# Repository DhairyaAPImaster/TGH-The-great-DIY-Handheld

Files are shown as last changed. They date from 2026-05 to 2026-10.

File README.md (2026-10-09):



# TGH - THE GREAT (DIY) HANDHELD
So yeah this is me trying to make my own custom retro handheld gaming device with a custom pcb powered by a pi zero 2w.

**BTW NOTE:** the case shall be printed by someone who was willing to print it from the slack channel - #printing-legion.

***very VERY IMPORTANT NOTE TO MACONDO REVIWER ---> SO IN THE BOM U MIGHT SEE THAT THE QTY OF SOME OF THE COMPONENTS FROM ROBU.IN IS MORE THAN REQUIRED THIS IS BECAUSE ROBU.IN HAS A MINIMUM ORDER QTY OF 10 INDIAN RUPEES PER COMPONENT SO HENCE I HAD TO LIKE INCREASE THE QTY OF SOME OF THE PASIVE COMPOENNTS TO LIKE FOLLOW THIS. BTW ITS STILL LIKE WAY WAY CHEAPER THAN JLCPCB'S PCBA THAT WOULD HAVE BROUGHT THE TOTAL COST TO 199.56 USD EXCLUDING TAX (I CHECKED)***

## project layout

```
.
├── `Assembly Layered.step`
├── `Assembly.step`
├── `wiring diagram.png`
├── `Custom Firmware!!!!!!!!!!/`
│   ├── `Launcher.py`
│   ├── `roms/`
│   │   ├── `GB/`
│   │   ├── `GBA/`
│   │   ├── `GBC/`
│   │   ├── `GEN/`
│   │   ├── `NES/`
│   │   ├── `SMS/`
│   │   └── `SNES/`
│   ├── `saves/`
│   └── `states/`
├── `production files/`
│   ├── `CAD/`
│   └── `PCB/`
│       ├── `MAIN PANELISED PCB (TO BE MANUFACTURED)/`
│       ├── `Mother board (not to be manufactured)/`
│       ├── `left daughter board (not to be manufactured)/`
│       └── `right daughter board (not to be manufactured)/`
└── `src/`
		├── `FreeCAD/`
		└── `PCB/`

```

## quick specs
- Panelised PCB Dimensions - 339.82 mm x 102.32 mm
- the only KiCAD plugin i used was KiKit to panelise the board, everything else was designed by me (this is my first major PCB project)

## WIRING DIAGRAM



## HOW TO RECREATE THIS PROJECT YOURSELF!!! 
- Step 1 - Basically Just Clone or downlaod this repo from github. U can do this by either going to the code button on this repo page and pressing download Zip or u can clone this Repo.
- Step 2 - Upload the gerbers zip file in JLCPCB (or any other manufacturer) Place order Page (u will need to sign up to order but can get a quote without signing up on jlcpcb)
- Step 3 - Change the colour of the PCB in the options JLC gives (if u use JLC PCB most of the times canging colours does not add any charge acc to what i know)
- Step 4 - Select PCBA if u want JLCPCB to assemble the PCB for you (though it is way more expensive than just soldering everything yourself.)
- Step 5 - Upload the CPL and BOM files.(if you are getting pcba)
- Step 6 - Recheck the position of all components
- Step 7 - Add to cart and order the PCB!! **(if you are soldering the components yourself you will need to buy them from some other place im mainly using robu.in and some components froma amzon and others)**
- Step 8 - If you dont have a 3D PRINTER jlcpcb has a 3d printing service too caled JLC3DP so u can upload the files for the case there and get it printed too but if u have a 3d printer you can just print it youreslf and save a lot of money.
- Step 9 - Order strong epoxy glue or superglue that does not cause harm to the 3d printed case material (I will be using FeviQuick as it should not cause harm to PLA in which the case will be printed)
- Step 10 - WAIT WAIT WAIT for your parts to be delhivered
- Step 11 - Once you have the PCB you will need to connect the daughter boards to the main motherboard using wires or an FFC connector i will be using solid code jumper wires since they are the easiest.
- Step 12 - If you are hand soldering the components you need to hand solder them according to the PCB Design that you can find by opening the project in kicad.
- Step 13 - Once you have all the parts ready (PCB, CASE and the appropriate Glue) place the PCB in the Case (you might have to trim the spacers down a bit as i made the spacers high so that they arent to small as i can always cut higher spacers down but can not extend spacers that are short.)  Use hot glue to secure the PCB onto the Spacers (btw if you have a smaller 3d printer you will have to like print the case in parts or diagonaly as it is slightly bigger than like the a1 mini and others of that size)
- Step 14 - Once the PCB is secured inside the case glue the Top Part of the Case shut after attatching the button caps onto the switches and adjusting the spacing of the screen.
- Step 15 - BOOM  THERE YOU HAVE IT THE PHYSICAL HARDWARE IS DONE NOW THE FIRMWARE.....

- Step 16 - To run the firmware first flash RASPBERRY PI OS onto the raspberry pi

- Step 17 - Put the microSD card into the Raspberry Pi Zero 2 W and power it on. Give it a little bit of time to boot for the first time. If you are using the Pi by itself for the initial setup, connect it to a display and keyboard so you can configure everything.

- Step 18 - Clone this repository onto the Raspberry PiThen enter the firmware folder:

	`TGH-The-great-DIY-Handheld/"Custom Firmware!!!!!!!!!!`

	The firmware folder should look something like this:
	```
	Custom Firmware!!!!!!!!!!
	├── Launcher.py
	├── roms/
	│   ├── GB/
	│   ├── GBA/
	│   ├── GBC/
	│   ├── GEN/
	│   ├── NES/
	│   ├── SMS/
	│   └── SNES/
	├── saves/
	└── states/
	```

 - Step 19 - If everything is working correctly, the TGH launcher should start.

 - ALMOST LAST STEP - ADD YOUR ROMS to there respective folders in the firmware folder
	Basically:

	Game Boy ROM → `GB/`

	Game Boy Advance ROM → `GBA/`

	Game Boy Color ROM → `GBC/`

	Genesis ROM → `GEN/`

	NES ROM → `NES/`

	Sega Master System ROM → `SMS/`

	SNES ROM → `SNES/`

- TRUE LAST STEP - CONNECT EVERYTHING TO THE CUSTOM PCB

- **RECOMMENDED** - Before closing the case, test:

Does the Pi boot?
Does the display work?
Does the launcher start?
Do the buttons work?
Do the joysticks work?
Does audio work?
Does the speaker work?
Does the headphone jack work?
Does the power system work?
Do games launch?
Do saves/states work?

If all of those work (IF U DO IT CORRECTLY IT WILL WORK) THEN..... 
## BOOM!!!! YOU HAVE A WORKING RETRO HANDHELD GAMING DEVICE!!!!!!

## BOM/BILL OF MATERIALS (PARTS I NEED FUNDING FOR)

| Name | Purpose | Quantity | Total Cost (USD) | Link | Distributor |
|---|---|---|---|---|---|
| PCB from JLCPCB  | it is the main PCB and will connect all components to each other. (btw JLCPCB has min order qty for PCB as 5 so yeah) | 5 | 18.4 | https://cart.jlcpcb.com/ | JLCPCB |
| Raspberry Pi Zero | its basically the core of the whole project it shall basically run everything. | 1 | 19.08 | https://robu.in/product/raspberry-pi-zero-wireless-wh-pre-soldered-header/ | robu.in |
| 5 Inch Touch Screen HDMI Interface TFT LCD | to display. | 1 | 26.18 | https://robu.in/product/5-inch-touch-screen-hdmi-interface-display-module-tft-lcd-800x480-raspberry-pi-2-model-b-touch-pen/ | robu.in |
| Mini HDMI To HDMI Cable | to connect pi to display | 1 | 1.08 | https://robu.in/product/mini-hdmi-hdmi-cable-1-8-meter-round-high-quality-copper-clad-steel-black/ | robu.in |
| 10 uF capacitor | to decouple more  | 15 | 0.14 | https://robu.in/product/cs2012x7r106m100nre-samwha-10v-10uf-x7r-%c2%b120-0805-multilayer-ceramic-capacitors-mlcc-smd-smt-rohs/ | robu.in |
| 100nF capacitor | to decouple | 20 | 0.14 | https://robu.in/product/tcc0805x7r104k500dt-cctc-smt-ceramic-capacitors-0805-x7r-104k100nf%c2%b110-rated-voltage50v-thickness0-85mmtape/ | robu.in |
| 6x6x5mm tactile switches | to well be used as switches and for the buttons controlling everything. | 10 | 0.14 | https://robu.in/product/6x6x5mm-tactile-push-button-switch-pack-of-20/ | robu.in |
| MAX98358ETE | audio amplifier | 1 | 2.62 | https://robu.in/product/1-month-warranty-560/ | robu.in |
| MT3608  IC | to take a lower DC voltage and steps it up to a higher, adjustable DC voltage | 2 | 0.28 | https://robu.in/product/mt3608-xian-aerosemi-tech-boost-type-adjustable-2a-2v24v-sot-23-6-dc-dc-converters-rohs/ | robu.in |
| 33 µH BOURNS-SRR1260-330M-Power Inductor (SMD) | to stores energy in a magnetic field and resists changes in electrical current. | 1 | 0.67 | https://robu.in/product/srr1260-330m-bourns-srr1260-330m-power-inductor-smd-33-%c2%b5h-3-a-shielded-2-8-a-srr1260-series/ | robu.in |
| SOD-123 Schottky Diodes ROHS | used to allow current to flow in one direction. | 2 | 0.12 | https://robu.in/product/1n5819w-kexin-40v-600mv1a-1a-sod-123-schottky-diodes-rohs/ | robu.in |
| 100 ohm resistor | to resist current | 25 | 0.12 | https://robu.in/product/rc0805jr-07100rl-yageo-res-thick-film-0805-100-ohm-5-0-125w1-8w-%c2%b1100ppm-c-pad-smd-t-r/ | robu.in |
| 4.7k ohm resistor | to resist  | 29 | 0.12 | https://robu.in/product/yageo-4-7k-ohm-1-4w-0805-surface-mount-resistor-pack-of-50/ | robu.in |
| 10k ohm resistor | im legit tired of writing the same thing again for all the resistor but anyways ---> IT resists the flow of current. | 20 | 0.12 | https://robu.in/product/rc0805fr-0710kl-yageo-res-thick-film-0805-10k-ohm-1-0-125w1-8w-%c2%b1100ppm-c-pad-smd-t-r/ | robu.in |
| 20k ohm resistor | u are not gonna belive what this does ---> IT resists the flow of current.... | 29 | 0.12 | https://robu.in/product/rc0805fr-0720kl-yageo-res-thick-film-0805-20k-ohm-1-0-125w1-8w-%c2%b1100ppm-c-pad-smd-t-r/ | robu.in |
| 33k ohm resistor | to resist!!!!! | 20 | 0.12 | https://robu.in/product/rc0805fr-0733kl-yageo-res-thick-film-0805-33k-ohm-1-0-125w1-8w-%c2%b1100ppm-c-pad-smd-t-r/ | robu.in |
| 100k ohm 0805 resistor | to resist flow of current? | 23 | 0.12 | https://robu.in/product/yageo-100k-ohm-1-2w-0805-surface-mount-resistor-pack-of-50/ | robu.in |
| D6.3xL11mm Aluminum Electrolytic Capacitors | its a capacitor dude like it provides capacitance (idk what do i write under Purpose) | 4 | 0.18 | https://robu.in/product/16yxf100mefct16-3x11-rubycon-100uf-16v-%c2%b120-plugind6-3xl11mm-aluminum-electrolytic-capacitors-leaded-rohs/ | robu.in |
| 22µF SMT 0805 capacitor | To provide capacitance | 10 | 0.18 | https://robu.in/product/tcc0805x5r226k100ft-cctc-smt-ceramic-capacitors-0805-x5r-226k22%c2%b5f%c2%b110-rated-voltage10v-thickness1-25mmtape/ | robu.in |
| TP4056 1A Li-Ion Battery Charging Board | To charge the battery  | 1 | 0.17 | https://robu.in/product/tp4056-1a-li-ion-battery-charging-board-micro-usb-with-current-protection-type-c-connector/ | Robu.in |
| 1mm Pitch Pin headers | These are seperate as the previous headers are not 1mm pitch pin headers. | 1 | 0.21 | https://robu.in/product/1-month-warranty-884/ | Robu.in |
| 3.5mm Female Audio Jack Connector  | to attach headphones | 1 | 0.47 | https://evelta.com/3-5mm-female-audio-jack-connector-6pin-1/ | Evelta.com |
| ADS1115IDGSR - 16-Bit ADC 2, 4 Input 1 Sigma-Delta IC VSSOP-10 | to convert analog voltage signals into digital data  | 1 | 1.94 | https://evelta.com/ads1115idgsr-16-bit-adc-2-4-input-1-sigma-delta-ic-vssop-10/ | Evelta.com |
| PS2 Game Joystick Module | For the Joysticks | 2 | 0.82 | https://www.flyrobo.in/ps2_game_joystick_module_for_arduino | FlyRobo |
| Male and Female Header Connector Strip, Pack of 10, Breakable Strip | For the pin Headers (btw this was a cheap pack of 10 and is actually cheaper than buying each header individually) | 1 | 1.27 | https://www.amazon.in/gp/product/B0FQP3SN7H/ref=ox_sc_act_image_8?smid=ATNZHHWX66S9H&psc=1 | Amazon |
| SPDT Slide Switch Right Angle | TO turn on and off | 1 | 1.0 | https://www.amazon.in/gp/product/B0B434R6QF/ref=ox_sc_act_image_7?smid=A2JDRZEGU1IDE2&psc=1 | Amazon |
| 0.5Watt Power Audio Speaker | For sound | 1 | 1.21 | https://www.amazon.in/gp/product/B07MTK843Z/ref=ox_sc_act_image_6?smid=AJ6SIZC8YQDZX&psc=1 | Amazon |
| Isopropyl Alcohol | For cleaning Board after soldering. | 1 | 2.95 | https://www.amazon.in/gp/product/B0DXLCF467/ref=ox_sc_act_image_5?smid=A66YHFPLB5NLO&th=1 | Amazon |
| Tactile Push Button Switch Caps | To button | 1 | 2.34 | https://www.amazon.in/gp/product/B0DCP7J7R7/ref=ox_sc_act_image_4?smid=AOG7U64E0DVL2&psc=1 | Amazon |
| Jumper Wires | For fine adjustment if required | 1 | 1.66 | https://www.amazon.in/gp/product/B0CPFCRCHB/ref=ox_sc_act_image_3?smid=AJ6SIZC8YQDZX&th=1 | Amazon |
| Solder  | to solder | 1 | 8.37 | https://www.amazon.in/gp/product/B084RZWVXY/ref=ox_sc_act_image_2?smid=AVIYBMAJK8N56&th=1 | Amazon |
| Soldering Flux | Helping to solder. | 1 | 0.84 | https://www.amazon.in/gp/product/B0FV8HHBTN/ref=ox_sc_act_image_1?smid=A366YFPXO3CTI5&psc=1 | Amazon |

## fab note
- so i plan on using JLCPCB to actually get my boards manufactured (i checked and for the size of this project's pcb getting the pcb from robu.in is way more expensive than jlcpcb) but will be ASSEMBLING THE COMPONENTS BY HAND!!!!

## pics from while i was designing it
















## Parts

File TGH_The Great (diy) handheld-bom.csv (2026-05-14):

Name | Purpose | Quantity | Total Cost (USD) | Link | Distributor
Solder | I cant solder witout solder and i have like 1cm or so left as i used the rest before my soldering iron short cicuited. | 1 | 7.75 | https://www.amazon.in/SONEAK-Solder-Rosin-Electrical-Soldering/dp/B084RZWVXY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 | Amazon
Soldering Flux | To help solder and not have cold solder joints. | 1 | 0.83 | https://www.amazon.in/UNIVERSAL-HUB-Soldering-Electronics-components/dp/B0FV8HHBTN | Amazon
Soldering Iron | Mine short circuited and i need to solder a buch of stuff on the pcb which i cant without the iron | 1 | 3.02 | https://www.amazon.in/Temperature-Adjustable-Soldering-Heating-Extra/dp/B0DPVMRTXG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 | amazon
Soldering Helping hands | Too see what i am soldering and to help solder properly without burning anything by mistake. | 1 | 5.35 | https://robu.in/product/te-801-multi-function-led-magnifier-pcb-soldering-iron-stand-holder-table-magnifying-glass-35x-12x-w-2-led-light/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 | Robu.in
JST SH 2 pin Connector 2mm Pitch | to connect battery | 1 | 0.02 | https://robu.in/product/jst-sh-2-pin-connector-2mm-pitch/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 | Robu.in
Mini HDMI To HDMI Cable | to connect pi to display | 1 | 1.30 | https://robu.in/product/mini-hdmi-hdmi-cable-1-8-meter-round-high-quality-copper-clad-steel-black/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 | Robu.in
40mm 8Ω (ohm) 0.5Watt Power Audio Speaker - Multicolor | to produce sound | 1 | 1.66 | https://www.amazon.in/Electronic-Spices-Wired-Sound-Speakers/dp/B07MTK843Z | amazon
PS2 joystick module | Left and right joystick | 2 | 0.79 | https://www.flyrobo.in/ps2_game_joystick_module_for_arduino?tracking=ads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 | FlyRobo
000mAh 3.7V Micro LiPo Battery pack | To power the device | 1 | 5.64 | https://robu.in/product/nova-955465-4000mah-3-7v-lipo-battery-pack/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 | Robu.in
100 uF 10V Through Hole Electrolytic Capacitor | headphone blocking on PCB | 2 | 0.04 | https://robu.in/product/100-uf-10v-through-hole-electrolytic-capacitor-pack-of-20/?gad_source=1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 | Robu.in
3mm Green LED | To show charging finished | 1 | 0.02 | https://robu.in/product/5mm-green-surface-mount-led-pack-of-50/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 | Robu.in
3mm Red LED | To see the charging | 1 | 0.02 | https://robu.in/product/3mm-red-dip-led-pack-of-50/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 | Robu.in
6mm Tactile Push Button Switch 6x6 (Pack of 10) | For buttoning | 1 | 0.14 | https://robu.in/product/6x6x5-tactile-push-button-switch/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 | Robu.in
Slide switch SPDT | To switch on the device | 1 | 0.09 | https://robu.in/product/1-month-warranty-805/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 | Robu.in
USB Type C, 2.0, 16P, Receptacle, Horizontal,Top Mount, Thru-Hole | Charging | 1 | 0.80 | https://www.mouser.in/ProductDetail/GCT/USB4920-00-A?qs=vcFyY%252BOcAygpR4IfeDpXRQ%3D%3D | Mouser
1x5 2.54mm Female Right Angle Single Row Header Strip | For Connecting the left and right joystick Modules | 2 | 0.26 | https://www.sunrom.com/p/1x5-254mm-female-right-angle-single-row-header-strip | sunrom.com
1x2 male pin header 2.54mm | For supplying power to the display and speaker | 3 | 0.69 | https://robu.in/product/a2541wv-2p-9t-cjt-1x2-pin-2-54mm-180-single-row-pin-header-rohs/?gad_source=1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 | Robu.in
2.54MM 2x20 Pin Female Double Row Straight Long Header Strip | To connect the Pi to the PCB | 1 | 0.86 | https://robu.in/product/2-54mm-2x20-pin-female-double-row-straight-long-header-strip/?gad_source=1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 | Robu.in
5 Inch Touch Screen HDMI Interface | THE SCREEN To See what i am playing | 1 | 26.09 | https://robu.in/product/5-inch-touch-screen-hdmi-interface-display-module-tft-lcd-800x480-raspberry-pi-2-model-b-touch-pen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 | Robu.in
Raspberry Pi Zero 2W | This is basically the Brain of the device it shall run RetroPie | 1 | 18.81 | https://robu.in/product/raspberry-pi-zero-wireless-wh-pre-soldered-header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 | Robu.in
PCBA for bottom SMD components on PCB | PCB SMD comlponent assembly since idk how to solder SMD components :( | 2 | 78.32 | https://jlcpcb.com | JLCPCB
PCB (Motherboard, and both daughter boards) | Basically the heart of the device. These are the custom PCB's that i have made for the handheld gaming device these shall hold all components and connect them. | 5 | 18.00 | https://jlcpcb.com | JLCPCB

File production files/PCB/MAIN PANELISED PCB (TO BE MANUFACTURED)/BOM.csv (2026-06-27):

Id | Designator | Footprint | Quantity | Designation | Supplier and ref
1 | Battery_3.7V1 | PinHeader_1x02_P2.54mm_Vertical | 1 | Conn_01x02
2 | C3 | C_0805_2012Metric | 1 | 22µF
3 | C4 | C_0805_2012Metric | 1 | 22uF
4 | C5 | C_0805_2012Metric | 1 | 10uF
5 | C6 | C_0805_2012Metric | 1 | 100nF
6 | C7, C8 | CP_Radial_D6.3mm_P2.50mm | 2 | 100µF
7 | D3 | D_SOD-123 | 1 | 1N5819
8 | J1 | PinHeader_2x20_P2.54mm_Vertical | 1 | Conn_02x20_Odd_Even
9 | J2 | PinHeader_1x02_P2.54mm_Vertical | 1 | TP4056_Module
10 | J3 | PinSocket_1x05_P2.54mm_Horizontal | 1 | Joystick_Left
11 | J4 | PinSocket_1x05_P2.54mm_Horizontal | 1 | Joystick_Right
12 | J5 | PinHeader_1x02_P2.54mm_Vertical | 1 | Display_5V
13 | J6 | PinHeader_1x02_P2.54mm_Vertical | 1 | Speaker
14 | J7 | Jack_3.5mm_CUI_SJ-3523-SMT_Horizontal | 1 | AudioJack3_3.5mm
15 | J10, J13 | PinHeader_1x12_P1.00mm_Vertical | 2 | FCC Connector Left Board
16 | J11, J12 | PinHeader_1x12_P1.00mm_Vertical | 2 | FCC Connector Right Board
17 | L1 | L_Bourns_SRR1260 | 1 | 22uH
18 | R4 | R_0805_2012Metric | 1 | 100k
19 | R5 | R_0805_2012Metric | 1 | 33k
20 | R6, R7, R8, R9, R10, R11, R12, R13, R14, R15, R22, R23, R28, R29 | R_0805_2012Metric | 14 | 10k
21 | R18, R19 | R_0805_2012Metric | 2 | 4.7k
22 | R20, R21 | R_0805_2012Metric | 2 | 100
23 | R24, R25, R26, R27 | R_0805_2012Metric | 4 | 20k
24 | SW1 | SW_Slide_SPDT_Angled_CK_OS102011MA1Q | 1 | SW_SPDT
25 | SW2 | SW_PUSH_6mm_H5mm | 1 | Button_A
26 | SW3 | SW_PUSH_6mm_H5mm | 1 | Button_B
27 | SW4 | SW_PUSH_6mm_H5mm | 1 | Button_X
28 | SW5 | SW_PUSH_6mm_H5mm | 1 | Button_Y
29 | SW6 | SW_PUSH_6mm_H5mm | 1 | D-pad UP
30 | SW7 | SW_PUSH_6mm_H5mm | 1 | D-pad DOWN
31 | SW8 | SW_PUSH_6mm_H5mm | 1 | D-pad LEFT
32 | SW9 | SW_PUSH_6mm_H5mm | 1 | D-pad RIGHT
33 | SW12 | SW_PUSH_6mm_H5mm | 1 | Start
34 | SW13 | SW_PUSH_6mm_H5mm | 1 | Select
35 | U2 | SOT-23-6 | 1 | MT3608
36 | U3 | TSSOP-10_3x3mm_P0.5mm | 1 | ADS1115IDGS
37 | U4 | TQFN-16-1EP_3x3mm_P0.5mm_EP1.23x1.23mm | 1 | MAX98357A

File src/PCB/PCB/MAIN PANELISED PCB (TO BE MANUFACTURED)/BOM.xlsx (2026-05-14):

Comment | Designator | Footprint
Conn_01x02 | Battery_3.7V1 | PinHeader_1x02_P2.54mm_Vertical
22µF | C3 | C_0805_2012Metric
22uF | C4 | C_0805_2012Metric
10uF | C5 | C_0805_2012Metric
100nF | C6 | C_0402_1005Metric
100µF | C7, C8 | CP_Radial_D6.3mm_P2.50mm
1N5819 | D3 | D_SOD-123
Conn_02x20_Odd_Even | J1 | PinHeader_2x20_P2.54mm_Vertical
TP4056_Module | J2 | PinHeader_1x02_P2.54mm_Vertical
Joystick_Left | J3 | PinSocket_1x05_P2.54mm_Horizontal
Joystick_Right | J4 | PinSocket_1x05_P2.54mm_Horizontal
Display_5V | J5 | PinHeader_1x02_P2.54mm_Vertical
Speaker | J6 | PinHeader_1x02_P2.54mm_Vertical
AudioJack3_3.5mm | J7 | Jack_3.5mm_CUI_SJ-3523-SMT_Horizontal
Connector Left Board | J10, J13 | PinHeader_1x12_P1.00mm_Vertical
Connector Right Board | J11 | PinHeader_1x12_P1.00mm_Vertical
Connector Right Board | J12 | PinHeader_1x12_P1.00mm_Vertical
Joystick Module Left Board | JM1 | Joystick Module 40x27mm
Joystick Module right board | JM2 | Joystick Module 40x27mm
22uH | L1 | L_Bourns_SRR1260
100k | R4 | R_0402_1005Metric
33k | R5 | R_0402_1005Metric
10k | R6, R7, R8, R9, R10, R11, R12, R13, R14, R15, R22, R23, R28, R29 | R_0402_1005Metric
4.7k | R18, R19 | R_0402_1005Metric
100 | R20, R21 | R_0402_1005Metric
20k | R24, R25, R26, R27 | R_0402_1005Metric
SW_SPDT | SW1 | SW_Slide_SPDT_Angled_CK_OS102011MA1Q
Button_A | SW2 | SW_PUSH_6mm_H5mm
Button_B | SW3 | SW_PUSH_6mm_H5mm
Button_X | SW4 | SW_PUSH_6mm_H5mm
Button_Y | SW5 | SW_PUSH_6mm_H5mm
D-pad UP | SW6 | SW_PUSH_6mm_H5mm
D-pad DOWN | SW7 | SW_PUSH_6mm_H5mm
D-pad LEFT | SW8 | SW_PUSH_6mm_H5mm
D-pad RIGHT | SW9 | SW_PUSH_6mm_H5mm
Start | SW12 | SW_PUSH_6mm_H5mm
Select | SW13 | SW_PUSH_6mm_H5mm
MT3608 | U2 | SOT-23-6
ADS1115IDGS | U3 | TSSOP-10_3x3mm_P0.5mm
MAX98357A | U4 | TQFN-16-1EP_3x3mm_P0.5mm_EP1.23x1.23mm

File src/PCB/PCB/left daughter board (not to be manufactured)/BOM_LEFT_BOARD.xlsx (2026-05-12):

Comment | Designator | Footprint
Joystick_Left | J3 | PinSocket_1x05_P2.54mm_Horizontal
FCC Connector Left Board | J10 | PinHeader_1x12_P1.00mm_Vertical
Joystick Module right board | JM2 | Joystick Module 40x27mm
10k | R10, R11, R12, R13, R14, R15, R22, R23 | R_0402_1005Metric
20k | R24, R25 | R_0402_1005Metric
D-pad UP | SW6 | SW_PUSH_6mm_H5mm
D-pad DOWN | SW7 | SW_PUSH_6mm_H5mm
D-pad LEFT | SW8 | SW_PUSH_6mm_H5mm
D-pad RIGHT | SW9 | SW_PUSH_6mm_H5mm
Start | SW12 | SW_PUSH_6mm_H5mm
Select | SW13 | SW_PUSH_6mm_H5mm

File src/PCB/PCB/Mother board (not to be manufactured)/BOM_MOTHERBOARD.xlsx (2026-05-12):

Comment | Designator | Footprint
Conn_01x02 | Battery_3.7V1 | PinHeader_1x02_P2.54mm_Vertical
10µF | C1 | C_0805_2012Metric
4.7µF | C2 | C_0805_2012Metric
22µF | C3 | C_0805_2012Metric
22uF | C4 | C_0805_2012Metric
10uF | C5 | C_0805_2012Metric
100nF | C6 | C_0402_1005Metric
100µF | C7, C8 | CP_Radial_D6.3mm_P2.50mm
RED | D1 | LED_D3.0mm
Green | D2 | LED_D3.0mm
1N5819 | D3 | D_SOD-123
Conn_02x20_Odd_Even | J1 | PinHeader_2x20_P2.54mm_Vertical
USB_C_Receptacle_USB2.0_14P | J2 | USB_C_Receptacle_GCT_USB4085
Display_5V | J5 | PinHeader_1x02_P2.54mm_Vertical
Speaker | J6 | PinHeader_1x02_P2.54mm_Vertical
AudioJack3_3.5mm | J7 | Jack_3.5mm_CUI_SJ-3523-SMT_Horizontal
FCC Connector Right Board | J12 | PinHeader_1x12_P1.00mm_Vertical
FCC Connector Left Board | J13 | PinHeader_1x12_P1.00mm_Vertical
22uH | L1 | L_Bourns_SRR1260
2K | R1 | R_0402_1005Metric
1K | R2, R3 | R_0402_1005Metric
100k | R4 | R_0402_1005Metric
33k | R5 | R_0402_1005Metric
5.1k | R16, R17 | R_0402_1005Metric
4.7k | R18, R19 | R_0402_1005Metric
100 | R20, R21 | R_0402_1005Metric
SW_SPDT | SW1 | SW_Slide_SPDT_Angled_CK_OS102011MA1Q
TP4056-42-ESOP8 | U1 | SOIC-8-1EP_3.9x4.9mm_P1.27mm_EP2.41x3.3mm_ThermalVias
MT3608 | U2 | SOT-23-6
ADS1115IDGS | U3 | TSSOP-10_3x3mm_P0.5mm
MAX98357A | U4 | TQFN-16-1EP_3x3mm_P0.5mm_EP1.23x1.23mm

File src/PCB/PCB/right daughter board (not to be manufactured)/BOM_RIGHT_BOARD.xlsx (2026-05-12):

Comment | Designator | Footprint
Joystick_Right | J4 | PinSocket_1x05_P2.54mm_Horizontal
FCC Connector Right Board | J11 | PinHeader_1x12_P1.00mm_Vertical
Joystick Module Left Board | JM1 | Joystick Module 40x27mm
10k | R6, R7, R8, R9, R28, R29 | R_0402_1005Metric
20k | R26, R27 | R_0402_1005Metric
Button_A | SW2 | SW_PUSH_6mm_H5mm
Button_B | SW3 | SW_PUSH_6mm_H5mm
Button_X | SW4 | SW_PUSH_6mm_H5mm
Button_Y | SW5 | SW_PUSH_6mm_H5mm

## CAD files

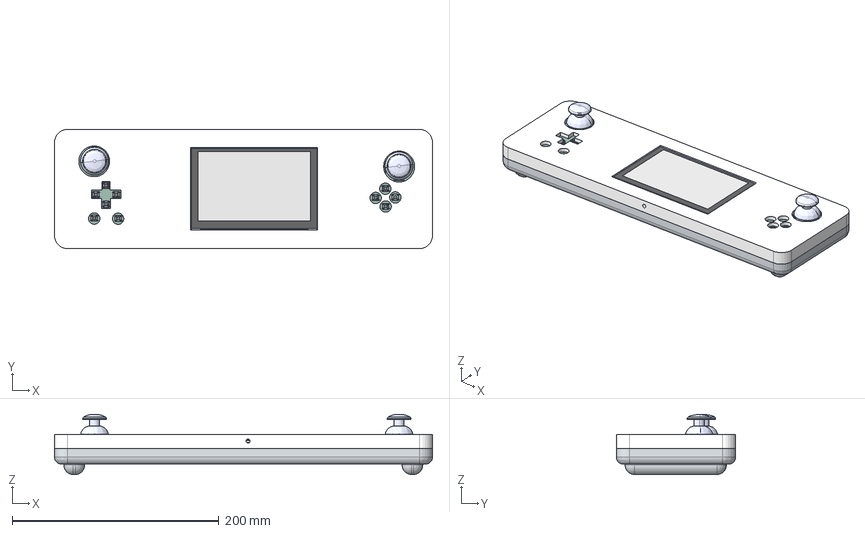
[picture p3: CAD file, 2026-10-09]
Assembly.step
365.3 x 115.3 x 58.0 mm
board
potentiometer___
potentiometer___001
tactileswitch-short
joystickhead___
Bottom Case
board001
potentiometer___002
potentiometer___003
tactileswitch-short001
joystickhead___001
Conector USB
Conector microUSB x 2
Jack_body
Jack_Pin1
Jack_Pin2
Jack_Pin3
5051102491 v1
User Library-QFP80_080 v1
PTS841GMSMTRLFS v1 x 5
4-40 3/4 inch bolt v2 x 4
5 inch lcd foot spacer v4 x 4
PinHeader_1x02_P2.54mm_Vertical x 4
PinHeader_1x12_P1.00mm_Vertical x 4
SW_PUSH_6mm_H5mm x 10
PinSocket_1x05_P2.54mm_Horizontal x 2
CP_Radial_D6.3mm_P2.50mm x 2
SW_Slide_SPDT_Angled_CK_OS102011MA1Q
PinHeader_2x20_P2.54mm_Vertical
R_0805_2012Metric x 24
C_0805_2012Metric x 4
SOT-23-6
L_Bourns_SRR1260
TSSOP-10_3x3mm_P0.5mm
D_SOD-123
Handheld_Panel_PCB

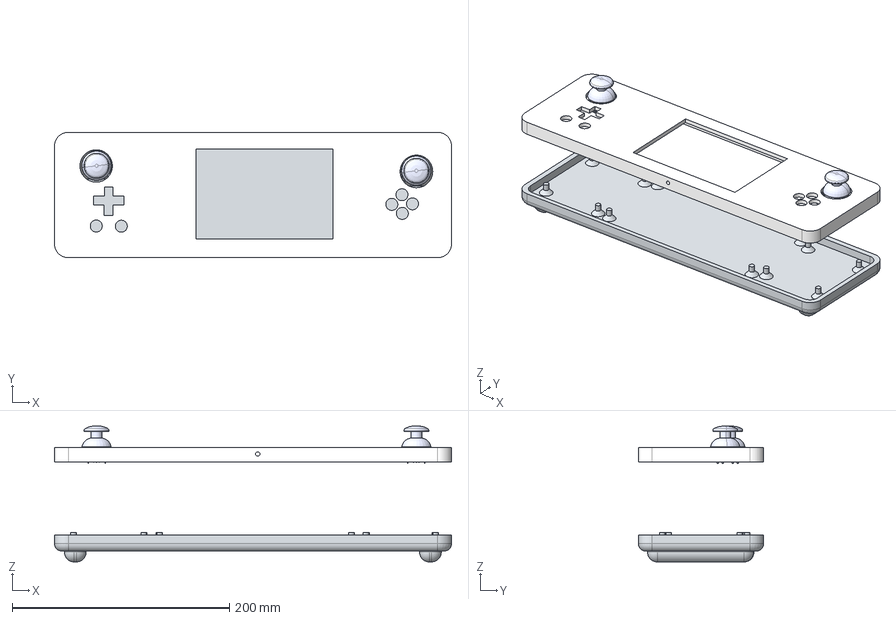
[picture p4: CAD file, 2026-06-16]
Assembly Layered.step
365.3 x 115.3 x 125.0 mm
Bottom Case
board
potentiometer___
potentiometer___001
tactileswitch-short
joystickhead___
board001
potentiometer___002
potentiometer___003
tactileswitch-short001
joystickhead___001

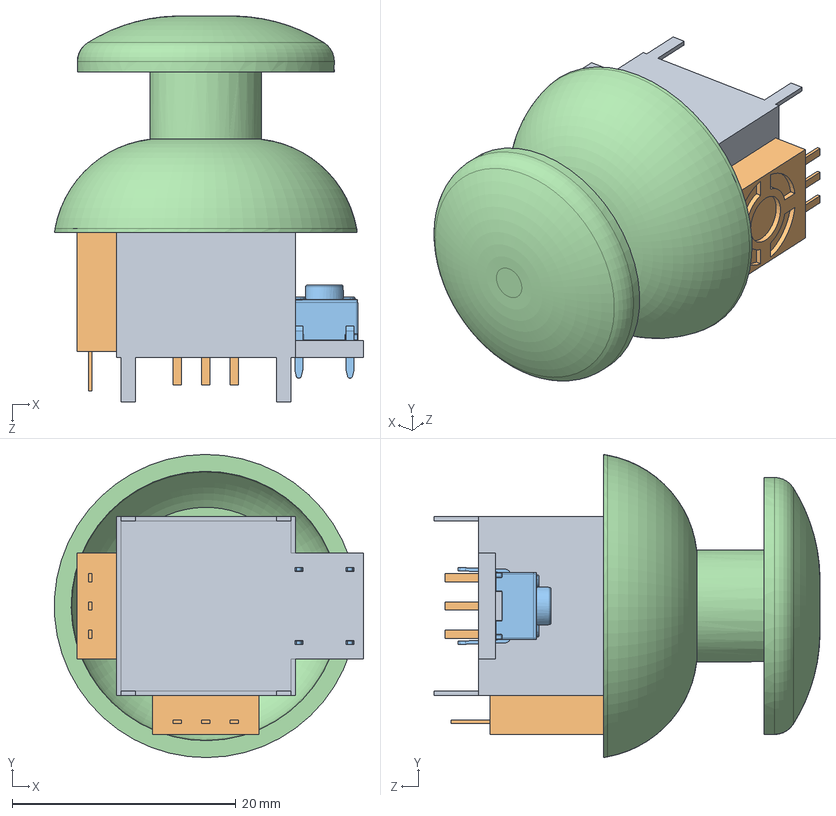
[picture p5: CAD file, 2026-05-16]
src/FreeCAD/dual-axis-xy-joystick-module-with-push-button-1.snapshot.1/Joystick/Thumb Joystick.SLDASM
27.6 x 27.1 x 34.5 mm
potentiometer x 2
tactileswitch-short
joystickhead

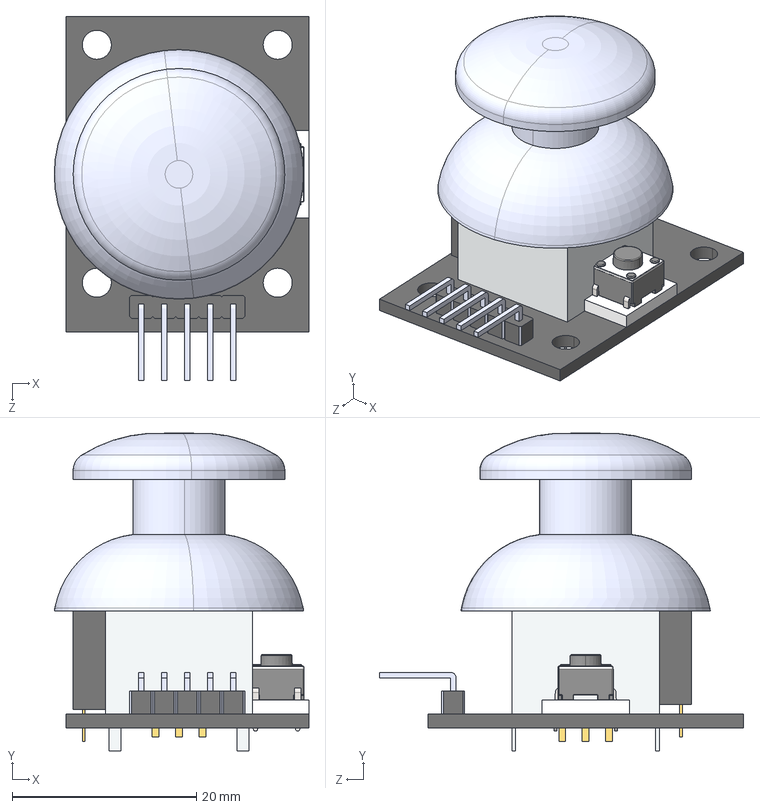
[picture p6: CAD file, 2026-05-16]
src/FreeCAD/dual-axis-xy-joystick-module-with-push-button-1.snapshot.1/Joystick/Joystick assembly.STEP
27.7 x 34.5 x 39.5 mm
board
potentiometer___ x 2
tactileswitch-short
joystickhead___

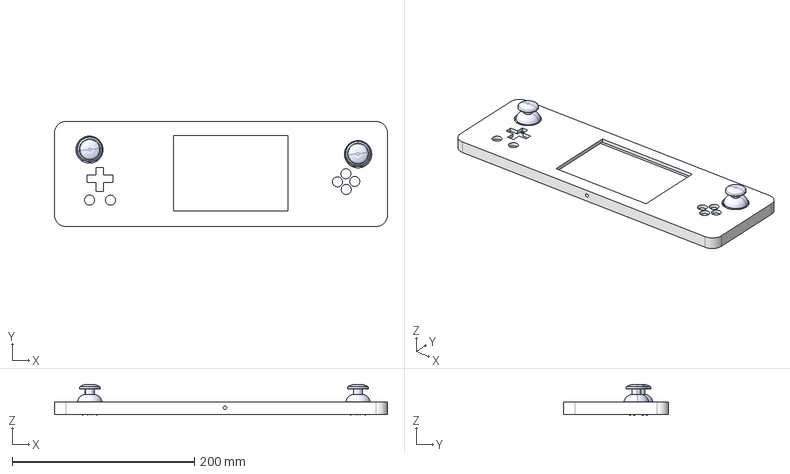
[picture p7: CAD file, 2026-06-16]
production files/CAD/Top Case.step
365.3 x 115.3 x 34.5 mm
board
potentiometer___
potentiometer___001
tactileswitch-short
joystickhead___
board001
potentiometer___002
potentiometer___003
tactileswitch-short001
joystickhead___001

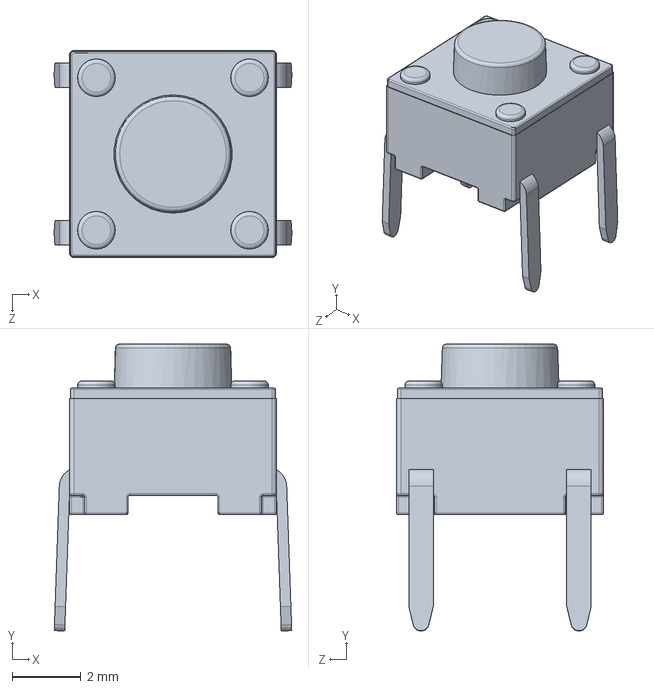
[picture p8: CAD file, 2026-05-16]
src/FreeCAD/dual-axis-xy-joystick-module-with-push-button-1.snapshot.1/Joystick/tactileswitch-short.SLDPRT
6.89 x 8.33 x 6.01 mm

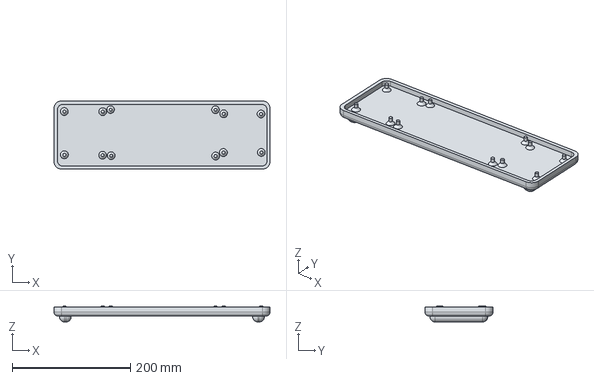
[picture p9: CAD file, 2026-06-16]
production files/CAD/Bottom Case.step
365.3 x 115.3 x 27.0 mm

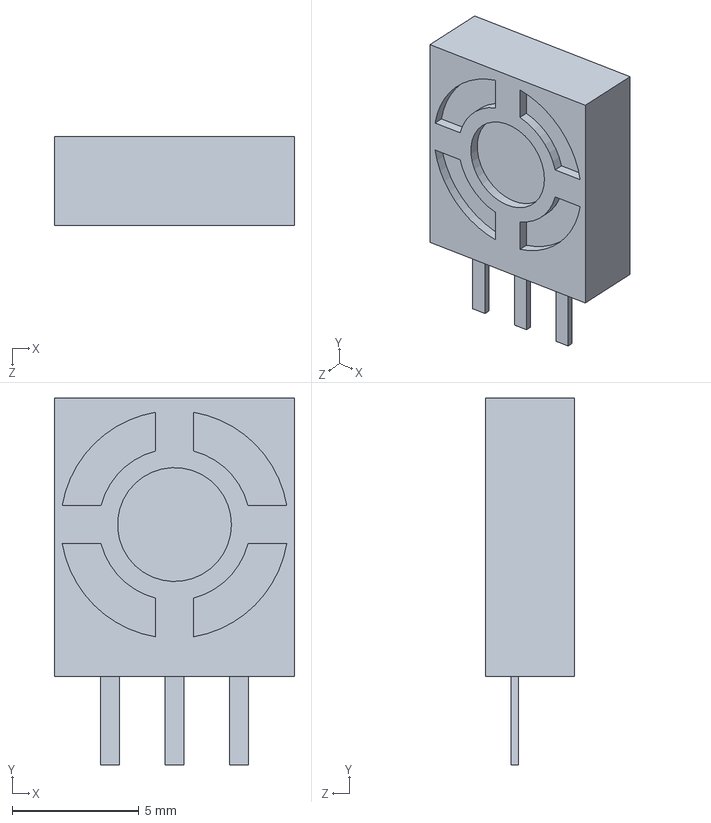
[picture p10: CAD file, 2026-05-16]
src/FreeCAD/dual-axis-xy-joystick-module-with-push-button-1.snapshot.1/Joystick/potentiometer.SLDPRT
9.50 x 14.5 x 3.50 mm

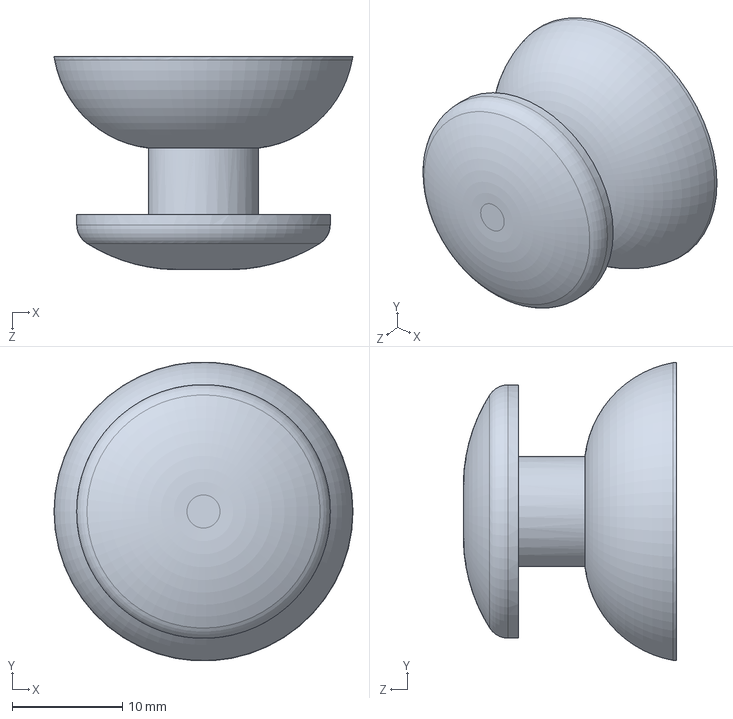
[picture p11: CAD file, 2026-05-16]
src/FreeCAD/dual-axis-xy-joystick-module-with-push-button-1.snapshot.1/Joystick/joystickhead.SLDPRT
27.1 x 27.1 x 19.3 mm

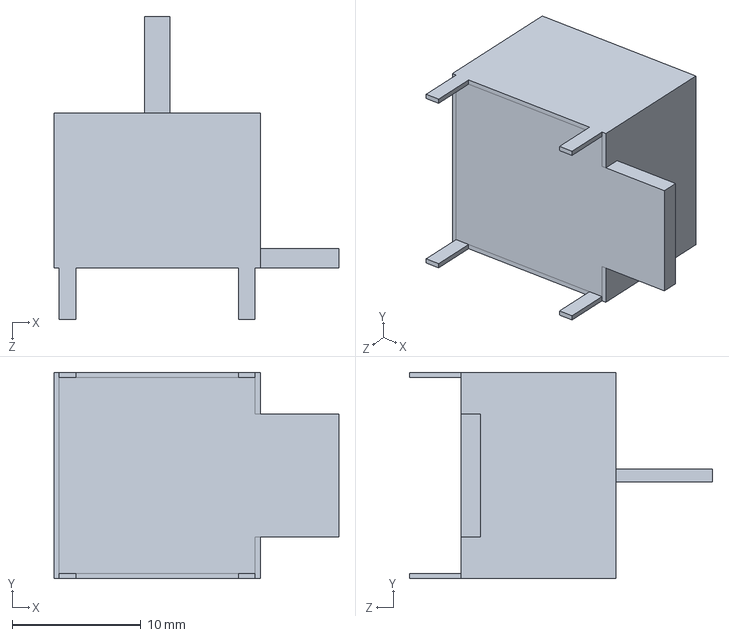
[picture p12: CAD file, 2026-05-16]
src/FreeCAD/dual-axis-xy-joystick-module-with-push-button-1.snapshot.1/Joystick/body.SLDPRT
22.1 x 16.0 x 23.5 mm

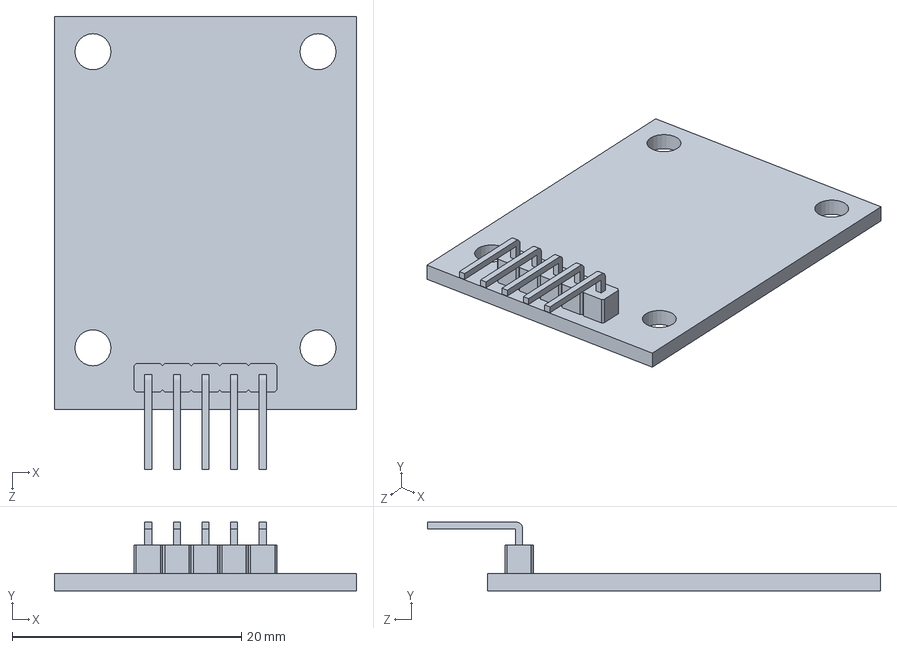
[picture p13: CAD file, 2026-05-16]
src/FreeCAD/dual-axis-xy-joystick-module-with-push-button-1.snapshot.1/Joystick/board.SLDPRT
26.4 x 6.01 x 39.5 mm

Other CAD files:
src/FreeCAD/Assembly.FCStd
Assembly Layered.stl
Assembly.stl
production files/CAD/Bottom Case.stl
production files/CAD/Top Case.stl
src/FreeCAD/dual-axis-xy-joystick-module-with-push-button-1.snapshot.1/Joystick/Joystick assembly.SLDASM

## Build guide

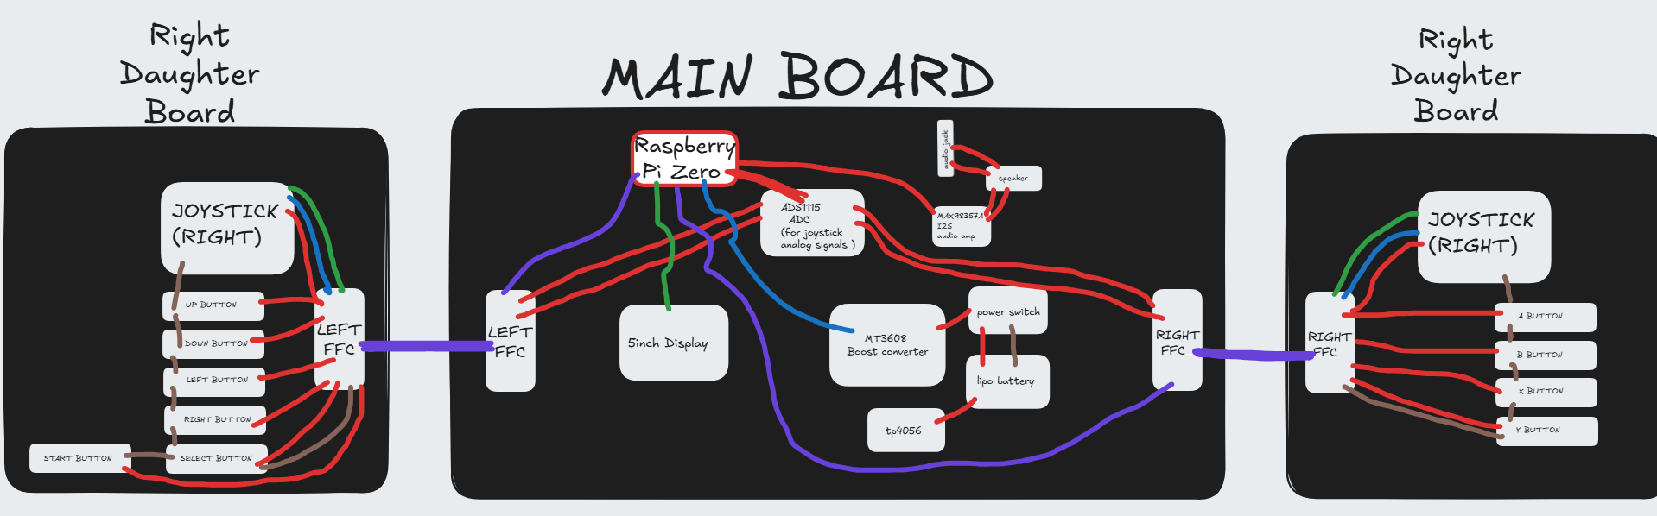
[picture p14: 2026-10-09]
wiring diagram.png

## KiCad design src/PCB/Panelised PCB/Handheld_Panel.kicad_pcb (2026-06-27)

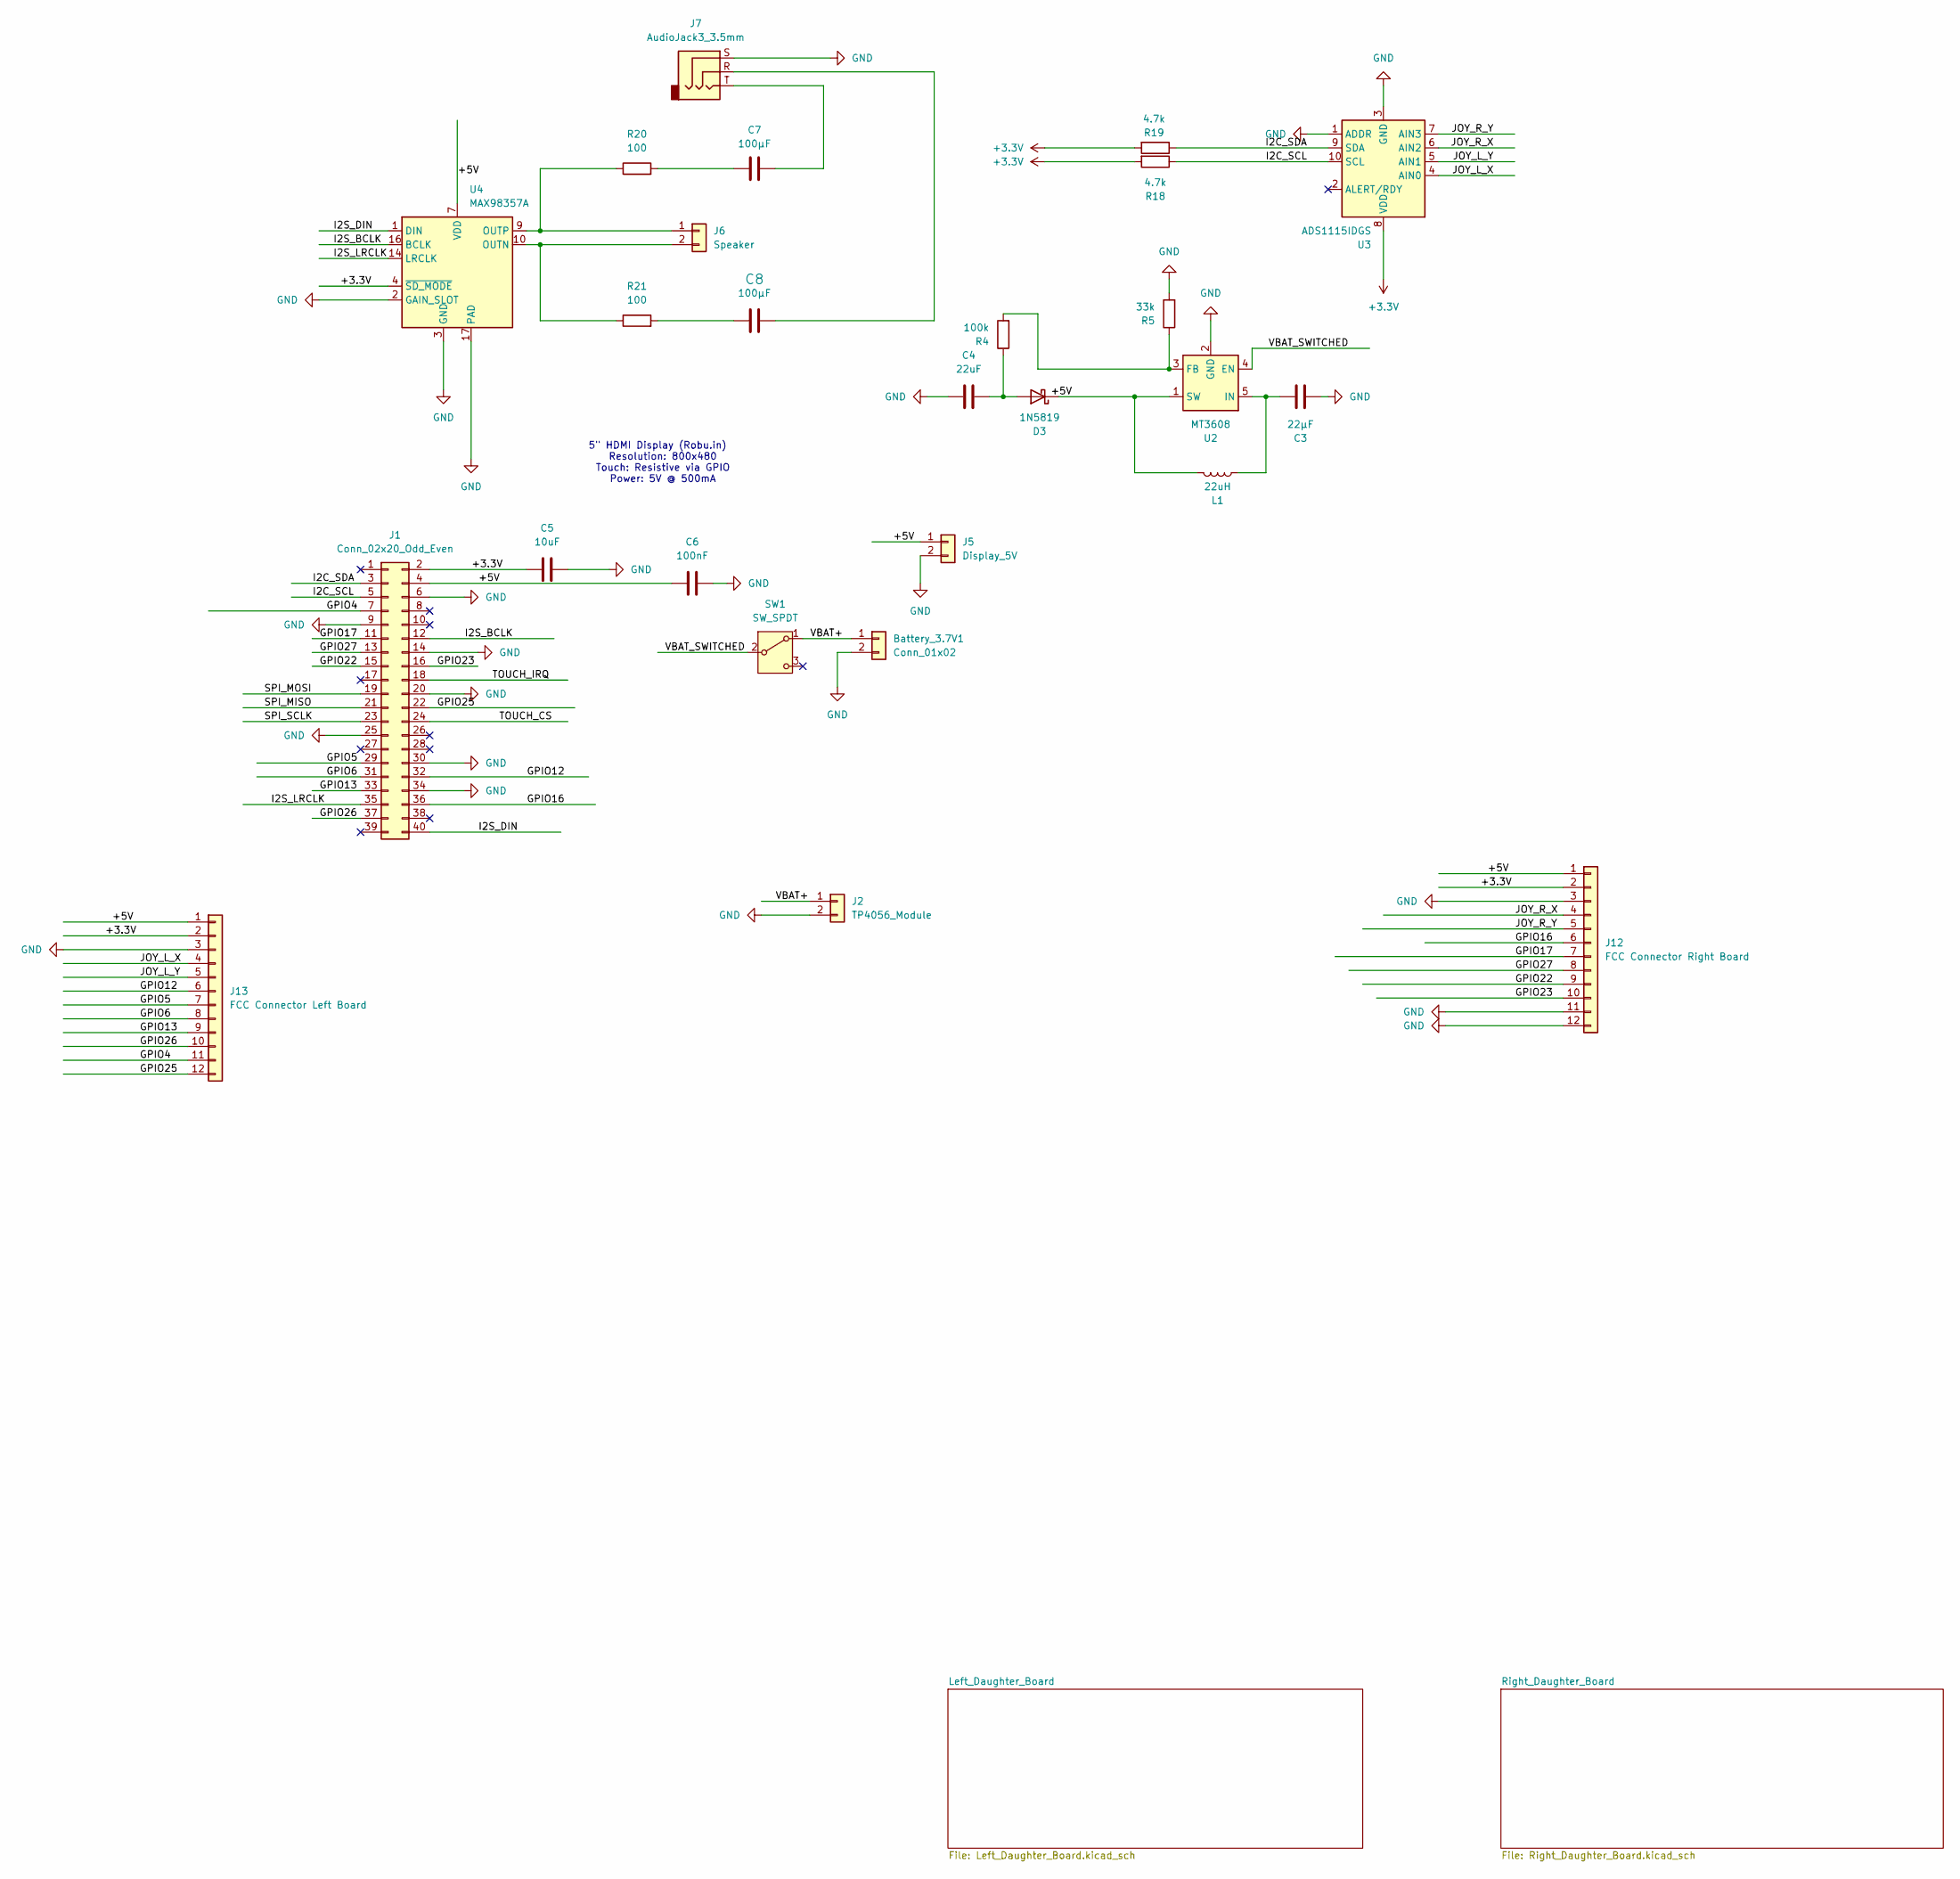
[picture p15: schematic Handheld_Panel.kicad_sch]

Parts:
Battery_3.7V1: Conn_01x02; PinHeader_1x02_P2.54mm_Vertical
C3: 22µF; C_0805_2012Metric
C4: 22uF; C_0805_2012Metric
C5: 10uF; C_0805_2012Metric
C6: 100nF; C_0805_2012Metric
C7, C8: 100µF; CP_Radial_D6.3mm_P2.50mm
D3: 1N5819; D_SOD-123
J1: Conn_02x20_Odd_Even; PinHeader_2x20_P2.54mm_Vertical
J2: TP4056_Module; PinHeader_1x02_P2.54mm_Vertical
J5: Display_5V; PinHeader_1x02_P2.54mm_Vertical
J6: Speaker; PinHeader_1x02_P2.54mm_Vertical
J7: AudioJack3_3.5mm; Jack_3.5mm_CUI_SJ-3523-SMT_Horizontal
J12: FCC Connector Right Board; PinHeader_1x12_P1.00mm_Vertical
J13: FCC Connector Left Board; PinHeader_1x12_P1.00mm_Vertical
L1: 22uH; L_Bourns_SRR1260
R4: 100k; R_0805_2012Metric
R5: 33k; R_0805_2012Metric
R18, R19: 4.7k; R_0805_2012Metric
R20, R21: 100; R_0805_2012Metric
SW1: SW_SPDT; SW_Slide_SPDT_Angled_CK_OS102011MA1Q
U2: MT3608; SOT-23-6
U3: ADS1115IDGS; TSSOP-10_3x3mm_P0.5mm
U4: MAX98357A; TQFN-16-1EP_3x3mm_P0.5mm_EP1.23x1.23mm

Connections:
+3.3V: C5.1, J1.2, J12.2, J13.2, R18.2, R19.2, U3.8 (VDD), U4.4 (~SD_MODE); also elsewhere on the board
/+5V: C6.1, D3.1 (K), J1.4, J5.1, J12.1, J13.1, L1.2, U2.1 (SW), U4.7 (VDD), U4.8 (VDD)
/GPIO4: J1.7, J13.11
/GPIO5: J1.29, J13.7
/GPIO6: J1.31, J13.8
/GPIO12: J1.32, J13.6
/GPIO13: J1.33, J13.9
/GPIO16: J1.36, J12.6
/GPIO17: J1.11, J12.7
/GPIO22: J1.15, J12.9
/GPIO23: J1.16, J12.10
/GPIO25: J1.22, J13.12
/GPIO26: J1.37, J13.10
/GPIO27: J1.13, J12.8
/I2C_SCL: J1.5, R18.1, U3.10 (SCL)
/I2C_SDA: J1.3, R19.1, U3.9 (SDA)
/I2S_BCLK: J1.12, U4.16 (BCLK)
/I2S_DIN: J1.40, U4.1 (DIN)
/I2S_LRCLK: J1.35, U4.14 (LRCLK)
/JOY_L_X: J13.4, U3.4 (AIN0)
/JOY_L_Y: J13.5, U3.5 (AIN1)
/JOY_R_X: J12.4, U3.6 (AIN2)
/JOY_R_Y: J12.5, U3.7 (AIN3)
/SPI_MISO: J1.21
/SPI_MOSI: J1.19
/SPI_SCLK: J1.23
/TOUCH_CS: J1.24
/TOUCH_IRQ: J1.18
/VBAT+: Battery_3.7V1.1, J2.1, SW1.1 (A)
/VBAT_SWITCHED: SW1.2 (B), U2.4 (EN)
GND: Battery_3.7V1.2, C3.1, C4.2, C5.2, C6.2, J1.6, J1.9, J1.14, J1.20, J1.25, J1.30, J1.34, J2.2, J5.2, J7.S, J12.3, J12.11, J12.12, J13.3, R5.2, U2.2 (GND), U3.1 (ADDR), U3.3 (GND), U4.2 (GAIN_SLOT), U4.3 (GND), U4.11 (GND), U4.15 (GND), U4.17 (PAD); also elsewhere on the board
unnamed: C7.1, R20.2
unnamed: C7.2, J7.T
unnamed: C8.1, R21.2
unnamed: C8.2, J7.R
unnamed: C4.1, D3.2 (A), R4.1
unnamed: J6.1, R20.1, U4.9 (OUTP)
unnamed: J6.2, R21.1, U4.10 (OUTN)
unnamed: R4.2, R5.1, U2.3 (FB)
unnamed: C3.2, L1.1, U2.5 (IN)

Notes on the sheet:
5" HDMI Display (Robu.in) Resolution: 800x480 Touch: Resistive via GPIO Power: 5V @ 500mA

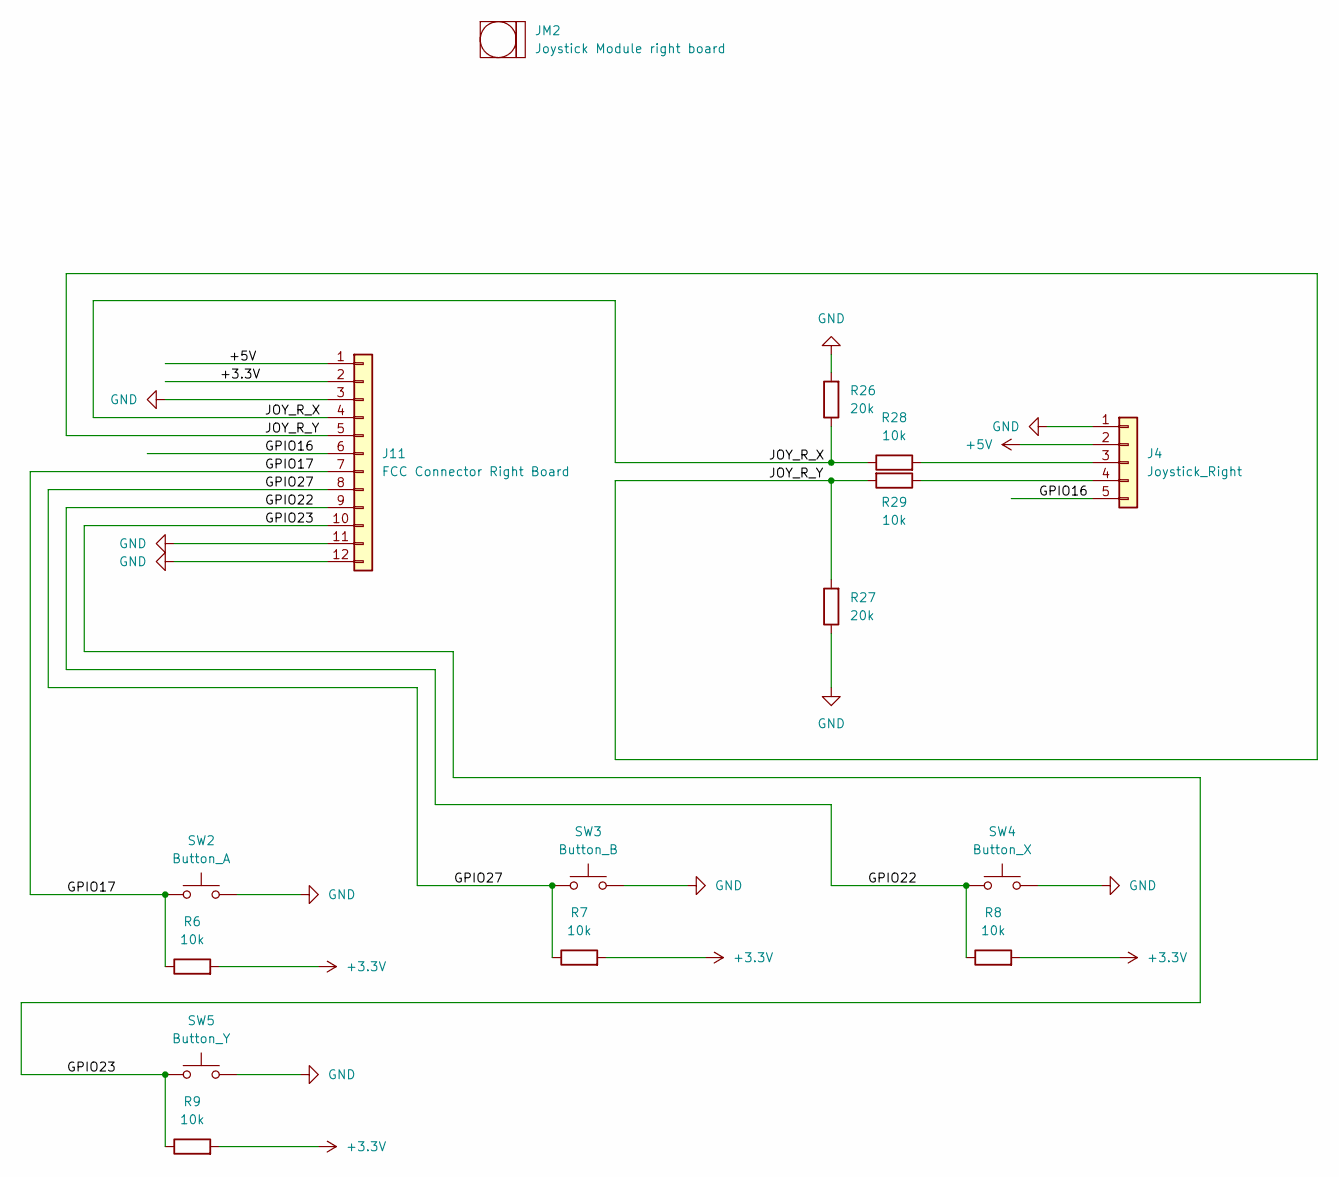
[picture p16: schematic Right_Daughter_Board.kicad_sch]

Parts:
J4: Joystick_Right; PinSocket_1x05_P2.54mm_Horizontal
J11: FCC Connector Right Board; PinHeader_1x12_P1.00mm_Vertical
JM2: Joystick Module right board; Joystick Module 40x27mm
R6, R7, R8, R9, R28, R29: 10k; R_0805_2012Metric
R26, R27: 20k; R_0805_2012Metric
SW2: Button_A; SW_PUSH_6mm_H5mm
SW3: Button_B; SW_PUSH_6mm_H5mm
SW4: Button_X; SW_PUSH_6mm_H5mm
SW5: Button_Y; SW_PUSH_6mm_H5mm

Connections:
+3.3V: J11.2, R6.2, R7.2, R8.2, R9.2; also elsewhere on the board
+5V: J4.2, J11.1; also elsewhere on the board
/Right_Daughter_Board/GPIO16: J4.5, J11.6
/Right_Daughter_Board/GPIO17: J11.7, R6.1, SW2.1
/Right_Daughter_Board/GPIO22: J11.9, R8.1, SW4.1
/Right_Daughter_Board/GPIO23: J11.10, R9.1, SW5.1
/Right_Daughter_Board/GPIO27: J11.8, R7.1, SW3.1
/Right_Daughter_Board/JOY_R_X: J11.4, R26.1, R28.1
/Right_Daughter_Board/JOY_R_Y: J11.5, R27.2, R29.2
GND: J4.1, J11.3, J11.11, J11.12, R26.2, R27.1, SW2.2, SW3.2, SW4.2, SW5.2; also elsewhere on the board
unnamed: J4.3, R28.2
unnamed: J4.4, R29.1

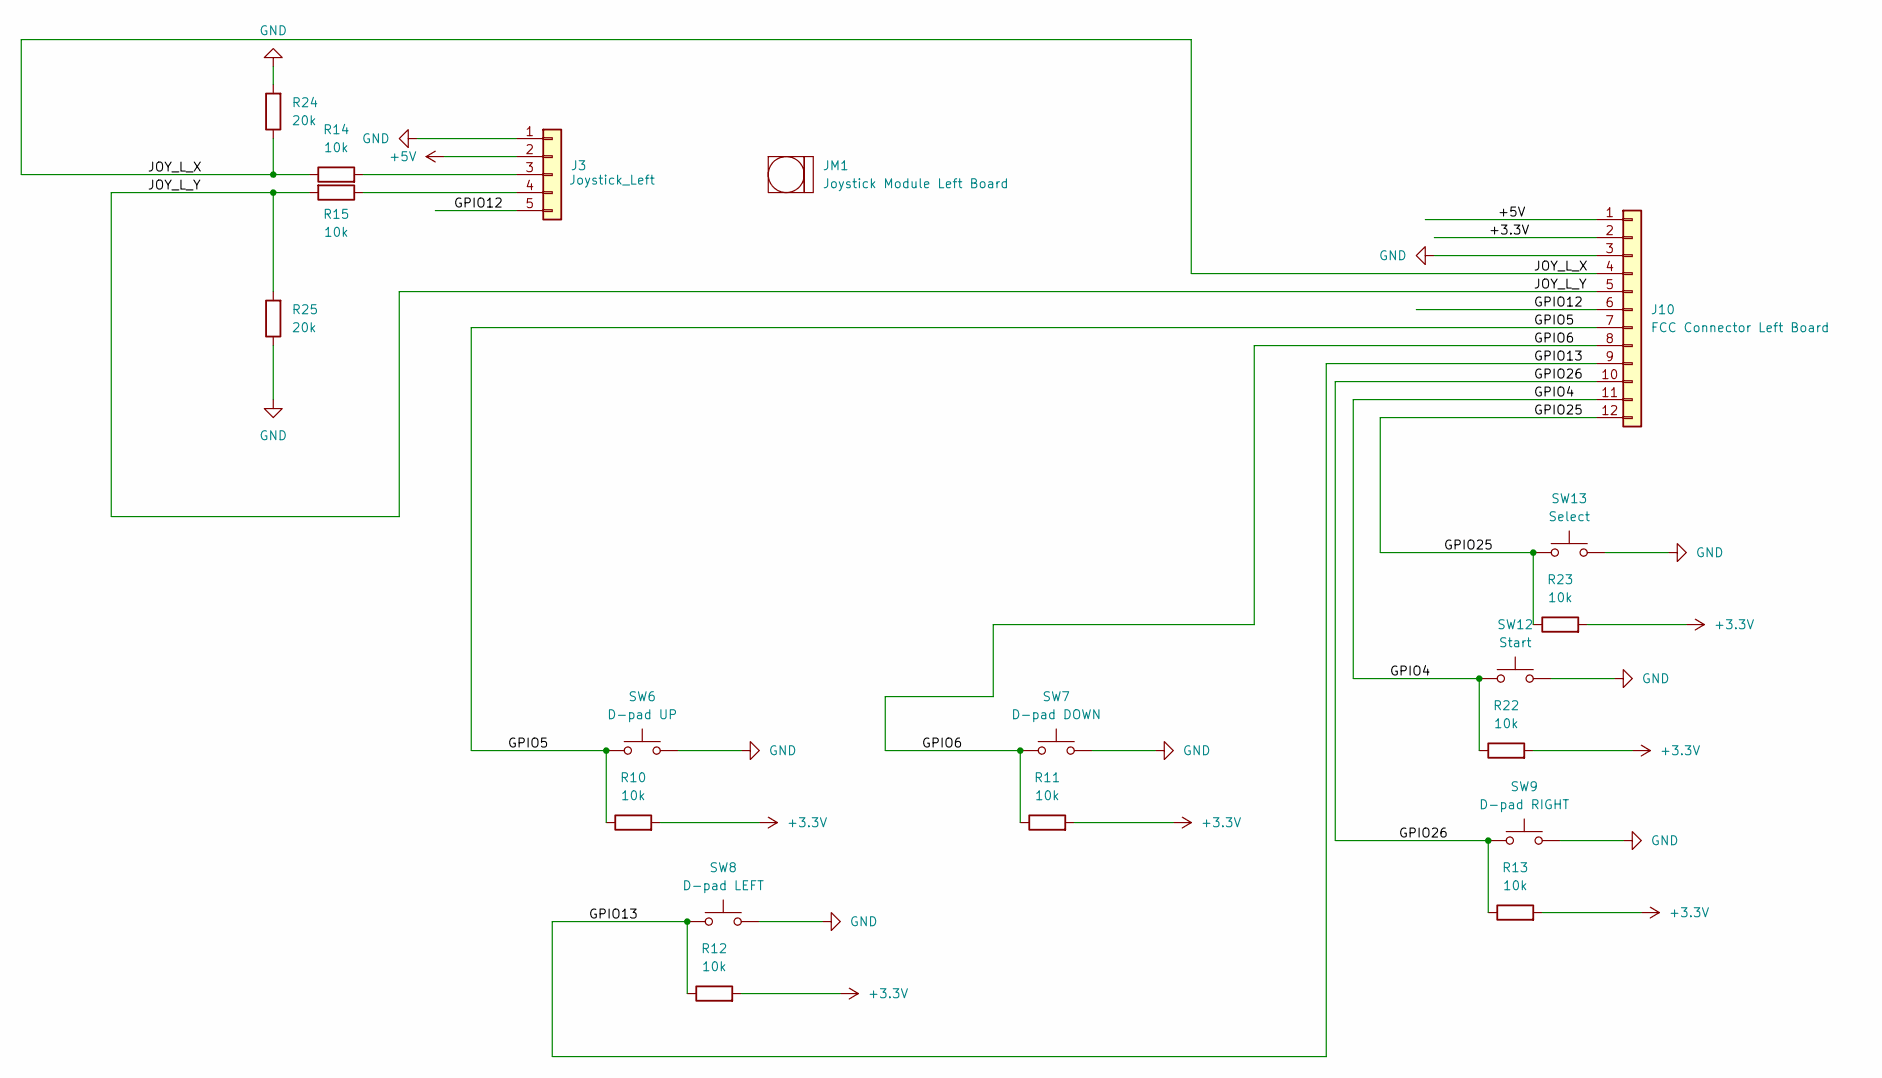
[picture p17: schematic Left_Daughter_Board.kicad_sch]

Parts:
J3: Joystick_Left; PinSocket_1x05_P2.54mm_Horizontal
J10: FCC Connector Left Board; PinHeader_1x12_P1.00mm_Vertical
JM1: Joystick Module Left Board; Joystick Module 40x27mm
R10, R11, R12, R13, R14, R15, R22, R23: 10k; R_0805_2012Metric
R24, R25: 20k; R_0805_2012Metric
SW6: D-pad UP; SW_PUSH_6mm_H5mm
SW7: D-pad DOWN; SW_PUSH_6mm_H5mm
SW8: D-pad LEFT; SW_PUSH_6mm_H5mm
SW9: D-pad RIGHT; SW_PUSH_6mm_H5mm
SW12: Start; SW_PUSH_6mm_H5mm
SW13: Select; SW_PUSH_6mm_H5mm

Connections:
+3.3V: J10.2, R10.2, R11.2, R12.2, R13.2, R22.2, R23.2; also elsewhere on the board
+5V: J3.2, J10.1; also elsewhere on the board
/Left_Daughter_Board/GPIO4: J10.11, R22.1, SW12.1
/Left_Daughter_Board/GPIO5: J10.7, R10.1, SW6.1
/Left_Daughter_Board/GPIO6: J10.8, R11.1, SW7.1
/Left_Daughter_Board/GPIO12: J3.5, J10.6
/Left_Daughter_Board/GPIO13: J10.9, R12.1, SW8.1
/Left_Daughter_Board/GPIO25: J10.12, R23.1, SW13.1
/Left_Daughter_Board/GPIO26: J10.10, R13.1, SW9.1
/Left_Daughter_Board/JOY_L_X: J10.4, R14.1, R24.1
/Left_Daughter_Board/JOY_L_Y: J10.5, R15.2, R25.2
GND: J3.1, J10.3, R24.2, R25.1, SW6.2, SW7.2, SW8.2, SW9.2, SW12.2, SW13.2; also elsewhere on the board
unnamed: J3.3, R14.2
unnamed: J3.4, R15.1

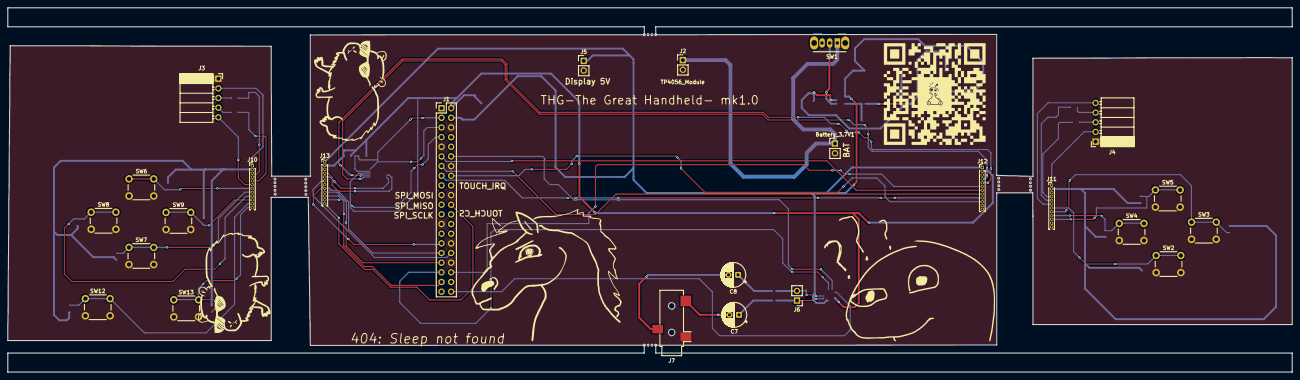
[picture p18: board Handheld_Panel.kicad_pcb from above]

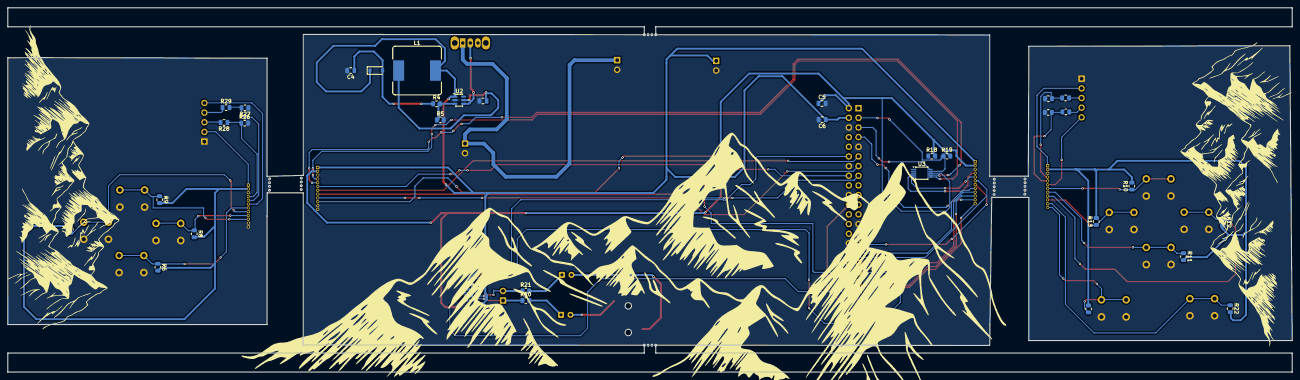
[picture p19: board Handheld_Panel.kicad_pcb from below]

Board: 2 copper layers, 337.8 x 95.8 mm, 85 parts (34 on the bottom side), 56 nets.

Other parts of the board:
KiKit_MB_1_1, KiKit_MB_1_2, KiKit_MB_1_2#2, KiKit_MB_1_2#3, KiKit_MB_1_2#4, KiKit_MB_1_2#5, KiKit_MB_1_2#6, KiKit_MB_1_2#7, KiKit_MB_1_2#8, KiKit_MB_1_2#9, KiKit_MB_1_3, KiKit_MB_1_3#2, KiKit_MB_1_3#3, KiKit_MB_1_3#4, KiKit_MB_1_3#5, KiKit_MB_1_3#6, KiKit_MB_1_3#7, KiKit_MB_1_3#8, KiKit_MB_1_3#9, KiKit_MB_1_3#10, KiKit_MB_1_3#11, KiKit_MB_1_4, KiKit_MB_2_1, KiKit_MB_2_2, KiKit_MB_2_3, KiKit_MB_2_4: NPTH
g: LOGO

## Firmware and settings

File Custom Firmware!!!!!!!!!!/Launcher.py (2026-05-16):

"""TGH custom game launcher for the handheld build."""

import pygame
import subprocess
import os
import sys
import time
import math
import random
import threading
# Hardware detection
GPIO_AVAILABLE = False
ADS_AVAILABLE  = False
try:
    import RPi.GPIO as GPIO
    GPIO_AVAILABLE = True
except ImportError:
    pass
try:
    import board
    import busio
    import adafruit_ads1x15.ads1115 as ADS
    from adafruit_ads1x15.analog_in import AnalogIn
    ADS_AVAILABLE = True
except ImportError:
    pass
# Configuration
# ROM paths
BASE_DIR    = os.path.dirname(os.path.abspath(__file__))
ROMS_PATH   = "/home/pi/roms" if GPIO_AVAILABLE else os.path.join(BASE_DIR, "roms")
SAVES_PATH  = "/home/pi/saves" if GPIO_AVAILABLE else os.path.join(BASE_DIR, "saves")
STATES_PATH = "/home/pi/states" if GPIO_AVAILABLE else os.path.join(BASE_DIR, "states")
# RetroArch path for Pi OS Lite
RETROARCH_PATH = "/usr/bin/retroarch"
CORES = {
    "NES":  "/opt/cores/fceumm_libretro.so",
    "SNES": "/opt/cores/snes9x_libretro.so",
    "GB":   "/opt/cores/gambatte_libretro.so",
    "GBC":  "/opt/cores/gambatte_libretro.so",
    "GBA":  "/opt/cores/mgba_libretro.so",
    "GEN":  "/opt/cores/genesis_plus_gx_libretro.so",
    "SMS":  "/opt/cores/genesis_plus_gx_libretro.so",
}
# Display info
SCREEN_WIDTH  = 800
SCREEN_HEIGHT = 480
FPS           = 60
# GPIO pin mapping
BTN_UP    = 5
BTN_DOWN  = 6
BTN_LEFT  = 13
BTN_RIGHT = 26
BTN_A     = 17
BTN_B     = 27
BTN_X     = 22
BTN_Y     = 23
BTN_START = 4
BTN_SEL   = 25
BTN_L1    = 12   # Left joystick button
BTN_R1    = 16   # Right joystick button

ALL_BTNS = [BTN_UP, BTN_DOWN, BTN_LEFT, BTN_RIGHT,
            BTN_A, BTN_B, BTN_X, BTN_Y,
            BTN_START, BTN_SEL, BTN_L1, BTN_R1]
# ADS1115 channel mapping
JOY_L_X_CH = 0   # AIN0
JOY_L_Y_CH = 1   # AIN1
JOY_R_X_CH = 2   # AIN2
JOY_R_Y_CH = 3   # AIN3
JOY_DEADZONE = 0.25
# Joystick center value (ADS1115 at 3.3V input = ~13107 at center with 5V joystick via divider)
JOY_CENTER   = 13107
JOY_MAX      = 26214
# AUDIO
AUDIO_ENABLED  = True
AUDIO_FREQ     = 44100
AUDIO_SIZE     = -16
AUDIO_CHANNELS = 2
AUDIO_BUFFER   = 512
VOLUME         = 0.8
# Color palette
C_BG      = (12,  12,  20)
C_WHITE   = (255, 255, 255)
C_GRAY    = (130, 130, 150)
C_DGRAY   = (35,  35,  50)
C_TEXT    = (220, 220, 235)
C_SEL_BG  = (28,  28,  45)
C_GREEN   = (80,  200, 100)
C_RED     = (220, 70,  70)
C_YELLOW  = (255, 200, 50)
C_BLUE    = (80,  120, 200)
# Systems
SYSTEMS = [
    {"id": "NES",  "short": "NES",
     "name": "Nintendo\nEntertainment\nSystem",
     "color": (220, 50,  50),
     "ext": [".nes"],
     "year": "1983"},
    {"id": "SNES", "short": "SNES",
     "name": "Super Nintendo\nEntertainment\nSystem",
     "color": (130, 80,  200),
     "ext": [".sfc", ".smc"],
     "year": "1990"},
    {"id": "GB",   "short": "GB",
     "name": "Game Boy",
     "color": (100, 160, 60),
     "ext": [".gb"],
     "year": "1989"},
    {"id": "GBC",  "short": "GBC",
     "name": "Game Boy\nColor",
     "color": (60,  180, 140),
     "ext": [".gbc"],
     "year": "1998"},
    {"id": "GBA",  "short": "GBA",
     "name": "Game Boy\nAdvance",
     "color": (80,  120, 200),
     "ext": [".gba"],
     "year": "2001"},
    {"id": "GEN",  "short": "SEGA",
     "name": "Sega\nGenesis",
     "color": (30,  144, 255),
     "ext": [".md", ".gen", ".bin"],
     "year": "1988"},
    {"id": "SMS",  "short": "SMS",
     "name": "Sega Master\nSystem",
     "color": (255, 140, 0),
     "ext": [".sms"],
     "year": "1985"},
]
# Helpers
def lerp(a, b, t):
    return a + (b - a) * t

def rr(surface, color, rect, radius, width=0):
    pygame.draw.rect(surface, color, rect, width, border_radius=radius)

def clamp(val, mn, mx):
    return max(mn, min(mx, val))

def get_games(system_id, extensions):
    games = []
    path  = os.path.join(ROMS_PATH, system_id)
    os.makedirs(path, exist_ok=True)
    if os.path.exists(path):
        for f in sorted(os.listdir(path)):
            if os.path.splitext(f)[1].lower() in extensions:
                games.append({
                    "name": os.path.splitext(f)[0],
                    "path": os.path.join(path, f),
                })
    return games

def get_battery():
    try:
        with open("/sys/class/power_supply/BAT0/capacity") as f:
            return int(f.read().strip())
    except:
        return None

def get_cpu_temp():
    try:
        with open("/sys/class/thermal/thermal_zone0/temp") as f:
            return int(f.read().strip()) // 1000
    except:
        return None
# Audio manager
class AudioManager:
    def __init__(self):
        self.enabled = False
        self.volume  = VOLUME
        if AUDIO_ENABLED:
            try:
                pygame.mixer.pre_init(AUDIO_FREQ, AUDIO_SIZE,
                                      AUDIO_CHANNELS, AUDIO_BUFFER)
                pygame.mixer.init()
                self.enabled = True
                self.sounds  = {}
                self._gen_sounds()
            except Exception as e:
                print(f"Audio init failed: {e}")

    def _gen_sounds(self):
        """Build the short UI sounds."""
        if not self.enabled:
            return
        try:
            # Navigation
            self.sounds["nav"]    = self._make_beep(440, 0.05)
            # Select
            self.sounds["select"] = self._make_beep(880, 0.08)
            # Back
            self.sounds["back"]   = self._make_beep(220, 0.07)
            # Launch
            self.sounds["launch"] = self._make_beep(660, 0.15)
            # Error
            self.sounds["error"]  = self._make_beep(150, 0.1)
        except Exception as e:
            print(f"Sound gen failed: {e}")

    def _make_beep(self, freq, duration):
        """Create a short sine-wave beep."""
        import numpy as np
        sample_rate = AUDIO_FREQ
        samples     = int(sample_rate * duration)
        t           = [i / sample_rate for i in range(samples)]
        wave        = [int(32767 * 0.3 * math.sin(2 * math.pi * freq * s))
                       for s in t]
        # Fade out the tail.
        for i in range(min(100, samples)):
            wave[samples-1-i] = int(wave[samples-1-i] * (i/100))
        buf = bytes(sum(([v & 0xFF, (v >> 8) & 0xFF] for v in wave), []))
        sound = pygame.mixer.Sound(buffer=buf)
        sound.set_volume(self.volume)
        return sound

    def play(self, name):
        if self.enabled and name in self.sounds:
            try:
                self.sounds[name].play()
            except:
                pass

    def set_volume(self, vol):
        self.volume = clamp(vol, 0.0, 1.0)
        for s in self.sounds.values():
            s.set_volume(self.volume)
# Joystick manager
class JoystickManager:
    def __init__(self):
        self.available = False
        self.lx = 0.0
        self.ly = 0.0
        self.rx = 0.0
        self.ry = 0.0
        self._last_dir = None
        self._dir_timer = 0

        if ADS_AVAILABLE:
            try:
                i2c        = busio.I2C(board.SCL, board.SDA)
                ads        = ADS.ADS1115(i2c)
                self.ch_lx = AnalogIn(ads, JOY_L_X_CH)
                self.ch_ly = AnalogIn(ads, JOY_L_Y_CH)
                self.ch_rx = AnalogIn(ads, JOY_R_X_CH)
                self.ch_ry = AnalogIn(ads, JOY_R_Y_CH)
                self.available = True
                print("ADS1115 joysticks initialized!")
            except Exception as e:
                print(f"ADS1115 init failed: {e}")

    def _read_axis(self, channel):
        """Read and normalize an axis to -1.0..1.0."""
        try:
            raw = channel.value
            norm = (raw - JOY_CENTER) / JOY_MAX
            norm = clamp(norm, -1.0, 1.0)
            if abs(norm) < JOY_DEADZONE:
                return 0.0
            return norm
        except:
            return 0.0

    def update(self):
        if not self.available:
            return
        self.lx = self._read_axis(self.ch_lx)
        self.ly = self._read_axis(self.ch_ly)
        self.rx = self._read_axis(self.ch_rx)
        self.ry = self._read_axis(self.ch_ry)

    def get_direction(self):
        """Return a direction from the left stick."""
        if not self.available:
            return None
        if self._dir_timer > 0:
            self._dir_timer -= 1
            return None
        if self.ly < -0.5:
            self._dir_timer = 15
            return "UP"
        if self.ly > 0.5:
            self._dir_timer = 15
            return "DOWN"
        if self.lx < -0.5:
            self._dir_timer = 15
            return "LEFT"
        if self.lx > 0.5:
            self._dir_timer = 15
            return "RIGHT"
        return None
# GPIO manager
class GPIOManager:
    def __init__(self):
        self.available = GPIO_AVAILABLE
        self._state    = {p: True for p in ALL_BTNS}
        self._prev     = {p: True for p in ALL_BTNS}

        if self.available:
            GPIO.setmode(GPIO.BCM)
            for pin in ALL_BTNS:
                if pin:
                    GPIO.setup(pin, GPIO.IN, pull_up_down=GPIO.PUD_UP)
            print("GPIO initialized!")

    def update(self):
        if not self.available:
            return
        self._prev = self._state.copy()
        for pin in ALL_BTNS:
            if pin:
                self._state[pin] = GPIO.input(pin)

    def pressed(self, pin):
        """True when the button transitions from released to pressed."""
        if not self.available or not pin:
            return False
        return not self._state[pin] and self._prev[pin]

    def held(self, pin):
        """True while the button is held down."""
        if not self.available or not pin:
            return False
        return not self._state[pin]

    def cleanup(self):
        if self.available:
            GPIO.cleanup()
# Main launcher
class Launcher:
    def __init__(self):
        pygame.init()
        pygame.mouse.set_visible(False)
        pygame.display.set_caption("TGH - The Great Handheld")

        flags = pygame.FULLSCREEN if GPIO_AVAILABLE else 0
        self.screen = pygame.display.set_mode(
            (SCREEN_WIDTH, SCREEN_HEIGHT), flags)
        self.clock  = pygame.time.Clock()

        # Fonts
        self.fXL = pygame.font.SysFont("Arial", 52, bold=True)
        self.fLG = pygame.font.SysFont("Arial", 34, bold=True)
        self.fMD = pygame.font.SysFont("Arial", 22, bold=True)
        self.fSM = pygame.font.SysFont("Arial", 17)
        self.fXS = pygame.font.SysFont("Arial", 13)

        # Hardware managers
        self.gpio  = GPIOManager()
        self.joy   = JoystickManager()
        self.audio = AudioManager()

        # State machine
        self.state      = "system_select"

        # System carousel
        self.sys_idx    = 0
        self.sys_anim   = 0.0

        # Game list
        self.game_idx   = 0
        self.scroll     = 0
        self.max_vis    = 7
        self.games      = []

        # Animation
        self.tick       = 0
        self.cooldown   = 0

        # Notification
        self.notif_text  = ""
        self.notif_timer = 0

        # Volume
        self.volume     = VOLUME

        # Confirm launch
        self.confirm_sel = 0  # 0=Yes 1=No

        # Star field
        self.stars = [
            (random.randint(0, SCREEN_WIDTH),
             random.randint(0, SCREEN_HEIGHT),
             random.random())
            for _ in range(70)
        ]

        # Init
        self.ensure_folders()
        self.reload_games()
        print("TGH Launcher initialized!")

    # Setup

    def ensure_folders(self):
        for s in SYSTEMS:
            os.makedirs(os.path.join(ROMS_PATH,  s["id"]), exist_ok=True)
        os.makedirs(SAVES_PATH,  exist_ok=True)
        os.makedirs(STATES_PATH, exist_ok=True)

    def reload_games(self):
        s = SYSTEMS[self.sys_idx]
        self.games    = get_games(s["id"], s["ext"])
        self.game_idx = 0
        self.scroll   = 0

    def notify(self, text, duration=120):
        self.notif_text  = text
        self.notif_timer = duration

    # Input
    def handle_input(self):
        if self.cooldown > 0:
            self.cooldown -= 1

        # Update hardware
        self.gpio.update()
        self.joy.update()

        # Pygame events for PC testing
        for event in pygame.event.get():
            if event.type == pygame.QUIT:
                return False
            if event.type == pygame.KEYDOWN:
                if not self.handle_key(event.key):
                    return False

        # GPIO input
        if GPIO_AVAILABLE:
            self._handle_gpio()

        # Joystick input
        joy_dir = self.joy.get_direction()
        if joy_dir and self.cooldown == 0:
            self._handle_direction(joy_dir)

        return True

    def handle_key(self, k):
        """Keyboard handler for PC testing."""
        if self.cooldown > 0:
            return True

        # Quit
        if k == pygame.K_q and not GPIO_AVAILABLE:
            return False

        # Direction keys
        dirs = {
            pygame.K_UP:    "UP",
            pygame.K_DOWN:  "DOWN",
            pygame.K_LEFT:  "LEFT",
            pygame.K_RIGHT: "RIGHT",
        }
        if k in dirs:
            self._handle_direction(dirs[k])
            return True

        # Action keys
        if self.state == "system_select":
            if k in (pygame.K_RETURN, pygame.K_SPACE):
                self._action_select()
            elif k == pygame.K_TAB:
                self.state = "library"
                self.audio.play("nav")
            elif k == pygame.K_s:
                self.state = "settings"
                self.audio.play("nav")

        elif self.state == "game_select":
            if k in (pygame.K_RETURN, pygame.K_SPACE):
                self._action_select()
            elif k == pygame.K_ESCAPE:
                self.state = "system_select"
                self.audio.play("back")
            elif k == pygame.K_r:
                self.reload_games()
                self.notify("Library refreshed!")

        elif self.state == "confirm_launch":
            if k == pygame.K_LEFT:
                self.confirm_sel = 0
            elif k == pygame.K_RIGHT:
                self.confirm_sel = 1
            elif k in (pygame.K_RETURN, pygame.K_SPACE):
                if self.confirm_sel == 0:
                    self._launch()
                else:
                    self.state = "game_select"
                    self.audio.play("back")
            elif k == pygame.K_ESCAPE:
                self.state = "game_select"
                self.audio.play("back")

        elif self.state in ("library", "settings"):
            if k in (pygame.K_ESCAPE, pygame.K_b):
                self.state = "system_select"
                self.audio.play("back")
            elif k == pygame.K_r and self.state == "library":
                self.reload_games()
                self.notify("Library refreshed!")

        # Volume control
        if k == pygame.K_PLUS or k == pygame.K_EQUALS:
            self._vol_up()
        elif k == pygame.K_MINUS:
            self._vol_down()

        return True

    def _handle_gpio(self):
        """Handle physical button presses."""
        if self.cooldown > 0:
            return

        # Direction buttons
        if self.gpio.pressed(BTN_UP):
            self._handle_direction("UP")
        elif self.gpio.pressed(BTN_DOWN):
            self._handle_direction("DOWN")
        elif self.gpio.pressed(BTN_LEFT):
            self._handle_direction("LEFT")
        elif self.gpio.pressed(BTN_RIGHT):
            self._handle_direction("RIGHT")

        # A button - select/confirm
        if self.gpio.pressed(BTN_A):
            self._action_select()
            self.cooldown = 15

        # B button - back
        if self.gpio.pressed(BTN_B):
            self._action_back()
            self.cooldown = 15

        # Start - go to game select
        if self.gpio.pressed(BTN_START):
            if self.state == "system_select":
                self._action_select()
            self.cooldown = 15

        # Select - toggle library
        if self.gpio.pressed(BTN_SEL):
            if self.state != "library":
                self.state = "library"
                self.audio.play("nav")
            else:
                self.state = "system_select"
                self.audio.play("back")
            self.cooldown = 15

        # X button - settings
        if self.gpio.pressed(BTN_X):
            if self.state != "settings":
                self.state = "settings"
                self.audio.play("nav")
            self.cooldown = 15

        # Y button - refresh
        if self.gpio.pressed(BTN_Y):
            self.reload_games()
            self.notify("Library refreshed!")
            self.cooldown = 15

        # L1 - volume down
        if self.gpio.pressed(BTN_L1):
            self._vol_down()
            self.cooldown = 8

        # R1 - volume up
        if self.gpio.pressed(BTN_R1):
            self._vol_up()
            self.cooldown = 8

    def _handle_direction(self, direction):
        """Handle directional input from buttons or joystick."""
        if self.cooldown > 0:
            return

        if self.state == "system_select":
            if direction == "LEFT":
                self.sys_idx = (self.sys_idx - 1) % len(SYSTEMS)
                self.reload_games()
                self.audio.play("nav")
                self.cooldown = 10
            elif direction == "RIGHT":
                self.sys_idx = (self.sys_idx + 1) % len(SYSTEMS)
                self.reload_games()
                self.audio.play("nav")
                self.cooldown = 10

        elif self.state == "game_select":
            if direction == "UP":
                self._prev_game()
                self.audio.play("nav")
                self.cooldown = 8
            elif direction == "DOWN":
                self._next_game()
                self.audio.play("nav")
                self.cooldown = 8
            elif direction == "LEFT":
                self.state = "system_select"
                self.audio.play("back")
                self.cooldown = 10

        elif self.state == "confirm_launch":
            if direction in ("LEFT", "RIGHT"):
                self.confirm_sel = 1 - self.confirm_sel
                self.audio.play("nav")
                self.cooldown = 8

        elif self.state == "settings":
            if direction == "UP":
                self._vol_up()
                self.cooldown = 8
            elif direction == "DOWN":
                self._vol_down()
                self.cooldown = 8

    def _action_select(self):
        """Handle A/Enter press."""
        if self.state == "system_select":
            if self.games:
                self.state = "game_select"
                self.audio.play("select")
            else:
                self.notify(f"No ROMs! Add to roms/{SYSTEMS[self.sys_idx]['id']}/")
                self.audio.play("error")

        elif self.state == "game_select":
            if self.games:
                self.state    = "confirm_launch"
                self.confirm_sel = 0
                self.audio.play("select")

        elif self.state == "confirm_launch":
            if self.confirm_sel == 0:
                self._launch()
            else:
                self.state = "game_select"
                self.audio.play("back")

    def _action_back(self):
        """Handle B/Escape press."""
        if self.state == "game_select":
            self.state = "system_select"
            self.audio.play("back")
        elif self.state == "confirm_launch":
            self.state = "game_select"
            self.audio.play("back")
        elif self.state in ("library", "settings"):
            self.state = "system_select"
            self.audio.play("back")

    def _prev_game(self):
        if not self.games:
            return
        self.game_idx = (self.game_idx - 1) % len(self.games)
        if self.game_idx < self.scroll:
            self.scroll = self.game_idx

    def _next_game(self):
        if not self.games:
            return
        self.game_idx = (self.game_idx + 1) % len(self.games)
        if self.game_idx >= self.scroll + self.max_vis:
            self.scroll = self.game_idx - self.max_vis + 1

    def _vol_up(self):
        self.volume = clamp(self.volume + 0.1, 0.0, 1.0)
        self.audio.set_volume(self.volume)
        self.notify(f"Volume: {int(self.volume*100)}%", 60)

    def _vol_down(self):
        self.volume = clamp(self.volume - 0.1, 0.0, 1.0)
        self.audio.set_volume(self.volume)
        self.notify(f"Volume: {int(self.volume*100)}%", 60)

    def _launch(self):
        if not self.games:
            return
        game   = self.games[self.game_idx]
        sys_id = SYSTEMS[self.sys_idx]["id"]
        core   = CORES.get(sys_id, "")

        self.audio.play("launch")

        if not os.path.exists(RETROARCH_PATH):
            self.notify(f"[PC TEST] Would launch: {game['name']}")
            self.state = "game_select"
            return

        # Launch RetroArch.
        pygame.quit()
        subprocess.run([
            RETROARCH_PATH,
            "-L", core,
            "--fullscreen",
            "--savestate-auto-load",
            game["path"]
        ])

        # Re-init after RetroArch exits.
        pygame.init()
        pygame.mouse.set_visible(False)
        self.screen = pygame.display.set_mode(
            (SCREEN_WIDTH, SCREEN_HEIGHT),
            pygame.FULLSCREEN if GPIO_AVAILABLE else 0
        )
        self.state = "game_select"
        self.notify(f"Welcome back!")
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

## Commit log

2026-05-12 changed the folder description to be more descriptive ig
    [BOM.csv, BOM_JLCPCB.xlsx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]
2026-05-12 Revise README with project specs and BOM
    Updated project details, specifications, and components list for the DIY handheld gaming device.
2026-05-12 Fix formatting issues in PCB BOM.csv
    Updated the PCB BOM file to correct formatting and ensure proper CSV structure.
    [PCB BOM.csv]
2026-05-14 changed the PCB to use the module instead of the chip
    [.stl, BOM.csv, BOM_JLCPCB.xlsx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]
2026-05-14 Update README with case printing note
    Added note about case printing from Slack channel.
2026-05-14 Clarify description for 6mm Tactile Buttons
    Updated the description for the 6mm Tactile Buttons.
2026-05-14 fixed the BOM
    [BOM.csv, PCB BOM.csv, PCB pannelised.stl]
2026-05-14 fixed the BOM and added details to the 3d case.
    [Bottom case-Body.step, Bottom case.FCStd, Button 1.stl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]
2026-05-14 final commit fixed BOM
    [BOM.csv]
2026-05-14 updated BOM
    [BOM.csv]
2026-05-14 added art on my PCB including a capybara and a horse that i drew myself!!!
    [Handheld Gaming device PCB.kicad_pcb, Handheld_Panel.kicad_pcb]
2026-05-14 fixed the orientation of the pcb art
    [Handheld_Panel.kicad_pcb]
2026-05-14 finally fixed the art on the PCB
    [Handheld_Panel.kicad_pcb]
2026-05-14 ok this time i finally fixed it with the mountains art on the back.
    [Handheld_Panel.kicad_pcb]
2026-05-14 last time i forgot to add the qr code on the PCB now it is there!!
    [Handheld_Panel.kicad_pcb]
2026-05-16 added custom firmware that shall run ontop of PiOS Lite as it has - RetroArch (emulators), Auto-start on boot, and can run my python launcher making a perfect handheld gaming device with custom firmw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
2026-05-16 Added a custom python firmware. Also made changes to the 3d Model to include the holes for the joysticls too!
    [Bottom case.FCStd, Joystick assembly.SLDASM, Joystick assembly.STEP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]
2026-06-16 changed the project structure to be organised and updated readME
    [Assembly Layered.FCStd, Assembly Layered.step, Assembly.FCStd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]
2026-06-24 ADDED VERY VERY IMPORTANT NOTE FOR STASIS PROJECT REVIEWER.
    Added important notes regarding PCBA and hand soldering limitations due to upcoming exams.
2026-06-24 fixed wrong PCB and PCBA price in the ReadME
2026-06-27 arranged the folder structure in a manner that is actually presentable.
    [BOM.csv, BOM.xlsx, BOM_LEFT_BOARD.xlsx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]
2026-06-27 fixed errors in like the PCB that i just now noticed
    [BOM.xlsx, BOM_LEFT_BOARD.xlsx, BOM_MOTHERBOARD.xlsx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]
2026-06-27 fixed stuff in the panelised PCB---> fixed the traces as many MANY were at like 90 degree angles and were kindoff messed up then also updated resistors and capacitors to 0805 size as i am planning on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
    [BOM.csv, BOM.xlsx, Handheld_Panel.kicad_pcb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]
2026-06-28 Revise BOM and assembly notes in README
    Updated BOM section to clarify component quantities and costs. Added notes regarding assembly and sourcing components.
2026-06-28 added .stl files
    [Assembly Layered.stl, Assembly.stl, Bottom Case.stl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]
2026-07-18 Update README with project recreation steps
    Added detailed steps for recreating the project and clarified the assembly process.
2026-08-08 added a bom.csv
    [bom.csv]
2026-08-08 Update README with firmware installation steps
    Added steps for firmware installation and testing for the Raspberry Pi setup.
2026-10-09 updated 3d assembly model
    [Assembly Layered.FCStd, Assembly.FCStd, Assembly.step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]
2026-10-09 added wiring diagram
